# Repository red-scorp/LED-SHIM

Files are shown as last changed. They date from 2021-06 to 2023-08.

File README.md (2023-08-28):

# LED-SHIM project

LED-SHIM (mini-HAT), RGB LED array for Raspberry Pi.

Sometimes it's nice to add some shine to your Pi.
This can be achieved with a line or matrix of RGB addressable LEDs.
Welcome to a new shiny world!

## LED-mini20-SHIM

Raspberry Pi mini 40-pin **LED-mini20-SHIM** mini-HAT.

Preview:

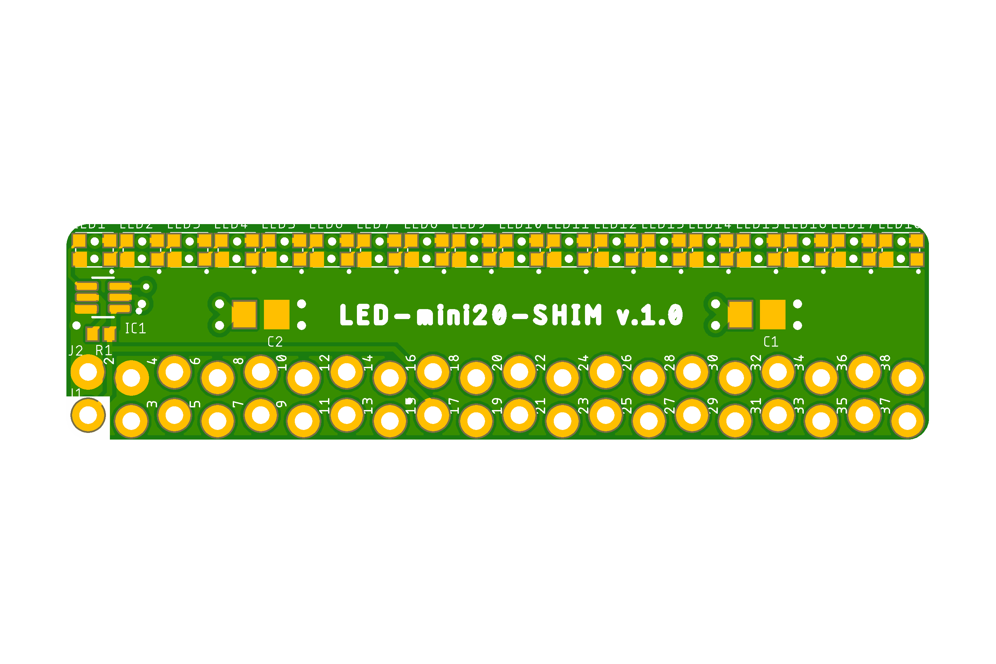
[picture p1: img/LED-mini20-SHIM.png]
LED-mini20-SHIM preview


[Schematics in PDF format](doc/LED-mini20-SHIM.pdf)

Features:

- locked Pi headers
- data input pin selection
- 18 RGB LEDs organized in a single line
- industry standard WS2812 addressable LEDs
- small board for Pi
- can be used as SHIM (no headers) or HAT (with headers)

Pins Configuration:

|Data Pin |Option 1 |Option 2 |Option 3 |
|---|---|---|---|
|DI |GPIO18\* |GPIO10 |GPIO21 |

\*) the pin is connected by default.

CAM files are available.
BoM and PnP files for JLCPCB are available.

## LED-mini35-SHIM

Raspberry Pi mini 40-pin **LED-mini35-SHIM** mini-HAT.

Preview:

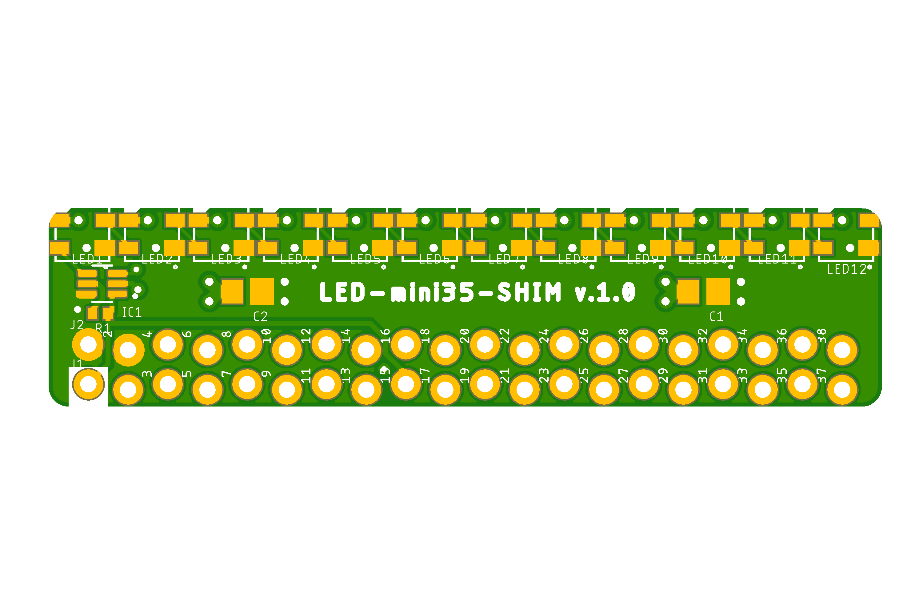
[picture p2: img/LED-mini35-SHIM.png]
LED-mini35-SHIM preview


[Schematics in PDF format](doc/LED-mini35-SHIM.pdf)

Features:

- locked Pi headers
- data input pin selection
- 12 RGB LEDs organized in a single line
- industry standard WS2812 addressable LEDs
- small board for Pi
- can be used as SHIM (no headers) or HAT (with headers)

Pins Configuration:

|Data Pin |Option 1 |Option 2 |Option 3 |
|---|---|---|---|
|DI |GPIO18\* |GPIO10 |GPIO21 |

\*) the pin is connected by default.

CAM files are available.
BoM and PnP files for JLCPCB are available.

## LED-zero20-SHIM

Raspberry Pi zero 40-pin **LED-zero20-SHIM** mini-HAT.

Preview:

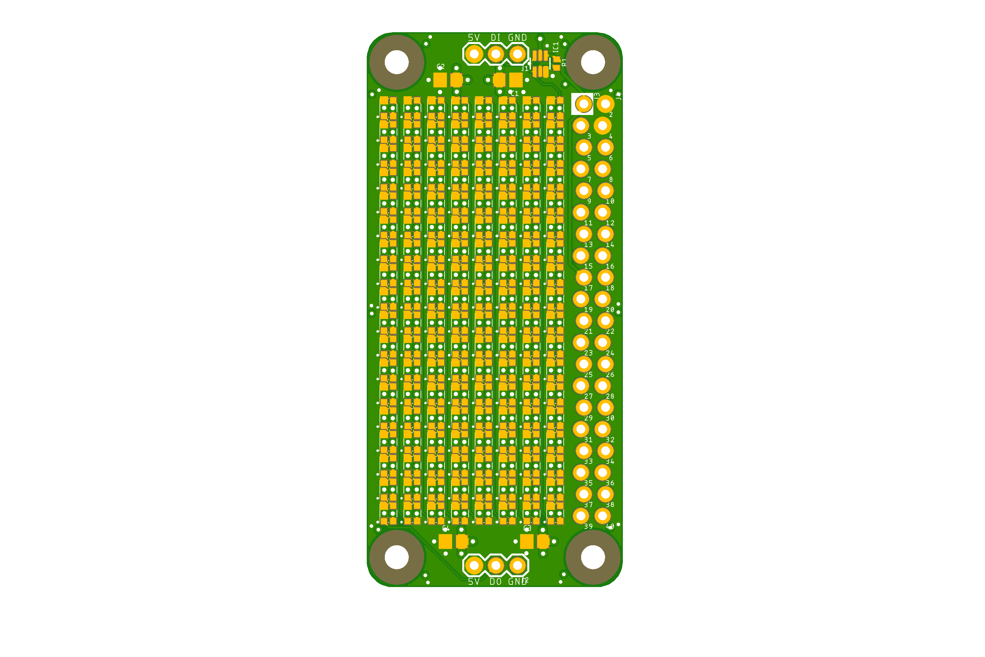
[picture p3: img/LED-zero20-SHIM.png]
LED-zero20-SHIM preview


[Schematics in PDF format](doc/LED-zero20-SHIM.pdf)

Features:

- locked Pi headers
- data input pin selection
- 144 RGB LEDs organized in a matrix of 18x8
- industry standard WS2812 addressable LEDs
- separate DI and DO headers for extendability
- Pi zero board style
- can be used as SHIM (no headers) or HAT (with headers)

Pins Configuration:

|Data Pin |Option 1 |Option 2 |Option 3 |
|---|---|---|---|
|DI |GPIO18\* |GPIO10 |GPIO21 |

\*) the pin is connected by default.

CAM files are available.
BoM and PnP files for JLCPCB are available.

## LED-zero35-SHIM

Raspberry Pi zero 40-pin **LED-zero35-SHIM** mini-HAT.

Preview:

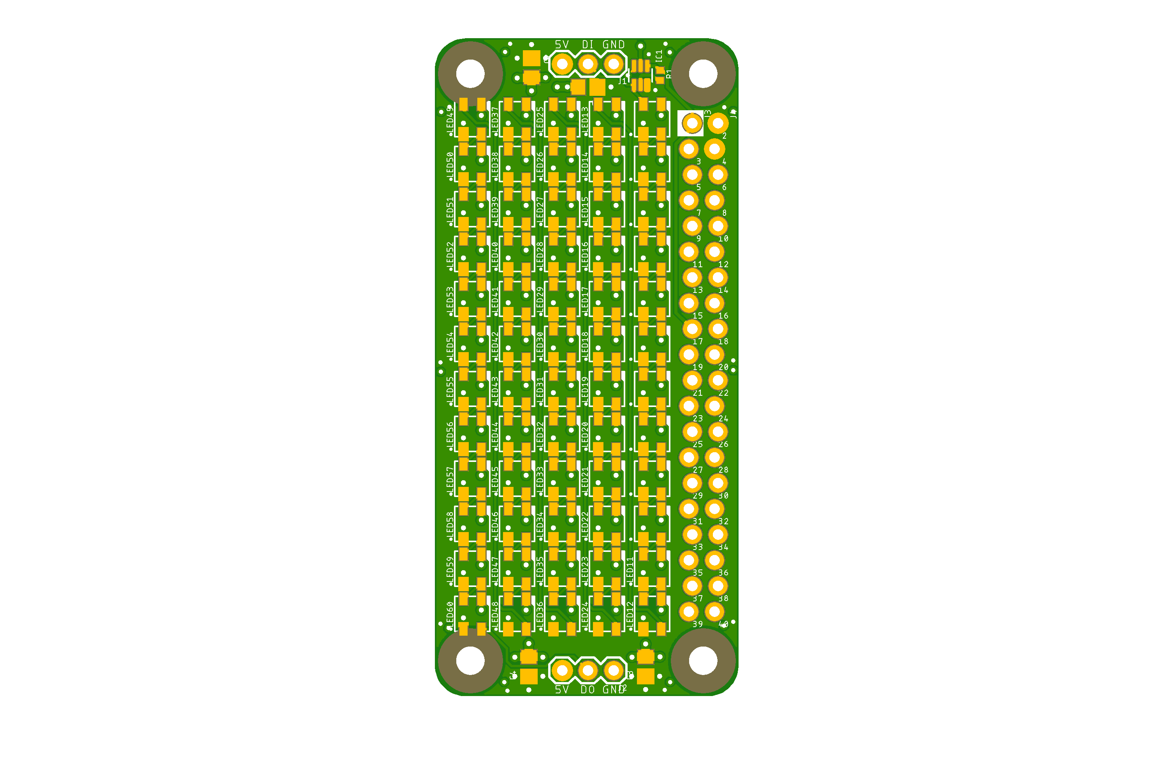
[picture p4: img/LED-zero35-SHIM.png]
LED-zero35-SHIM preview


[Schematics in PDF format](LED-zero35-SHIM.pdf)

Features:

- locked Pi headers
- data input pin selection
- 60 RGB LEDs organized in a matrix of 12x5
- industry standard WS2812 addressable LEDs
- separate DI and DO headers for extendability
- Pi zero board style
- can be used as SHIM (no headers) or HAT (with headers)

Pins Configuration:

|Data Pin |Option 1 |Option 2 |Option 3 |
|---|---|---|---|
|DI |GPIO18\* |GPIO10 |GPIO21 |

\*) the pin is connected by default.

CAM files are available.
BoM and PnP files for JLCPCB are available.

## LED-plus20-SHIM

Raspberry Pi plus 40-pin **LED-plus20-SHIM** mini-HAT.

Preview:

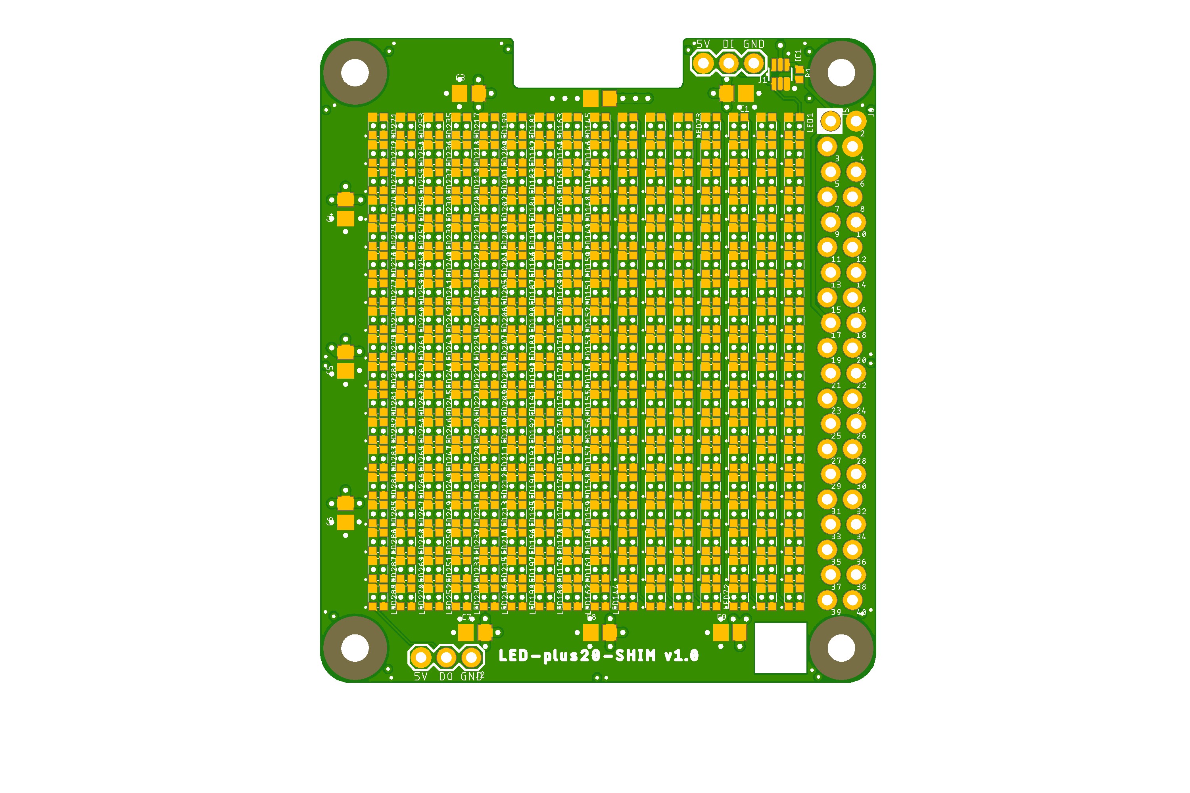
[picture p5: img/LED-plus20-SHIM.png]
LED-plus20-SHIM preview


[Schematics in PDF format](doc/LED-plus20-SHIM.pdf)

Features:

- locked Pi headers
- data input pin selection
- 288 RGB LEDs organized in a matrix of 18x16
- industry standard WS2812 addressable LEDs
- separate DI and DO headers for extendability
- Pi plus board style
- can be used as SHIM (no headers) or HAT (with headers)

Pins Configuration:

|Data Pin |Option 1 |Option 2 |Option 3 |
|---|---|---|---|
|DI |GPIO18\* |GPIO10 |GPIO21 |

\*) the pin is connected by default.

CAM files are available.
BoM and PnP files for JLCPCB are available.

## LED-plus35-SHIM

Raspberry Pi plus 40-pin **LED-plus35-SHIM** mini-HAT.

Preview:

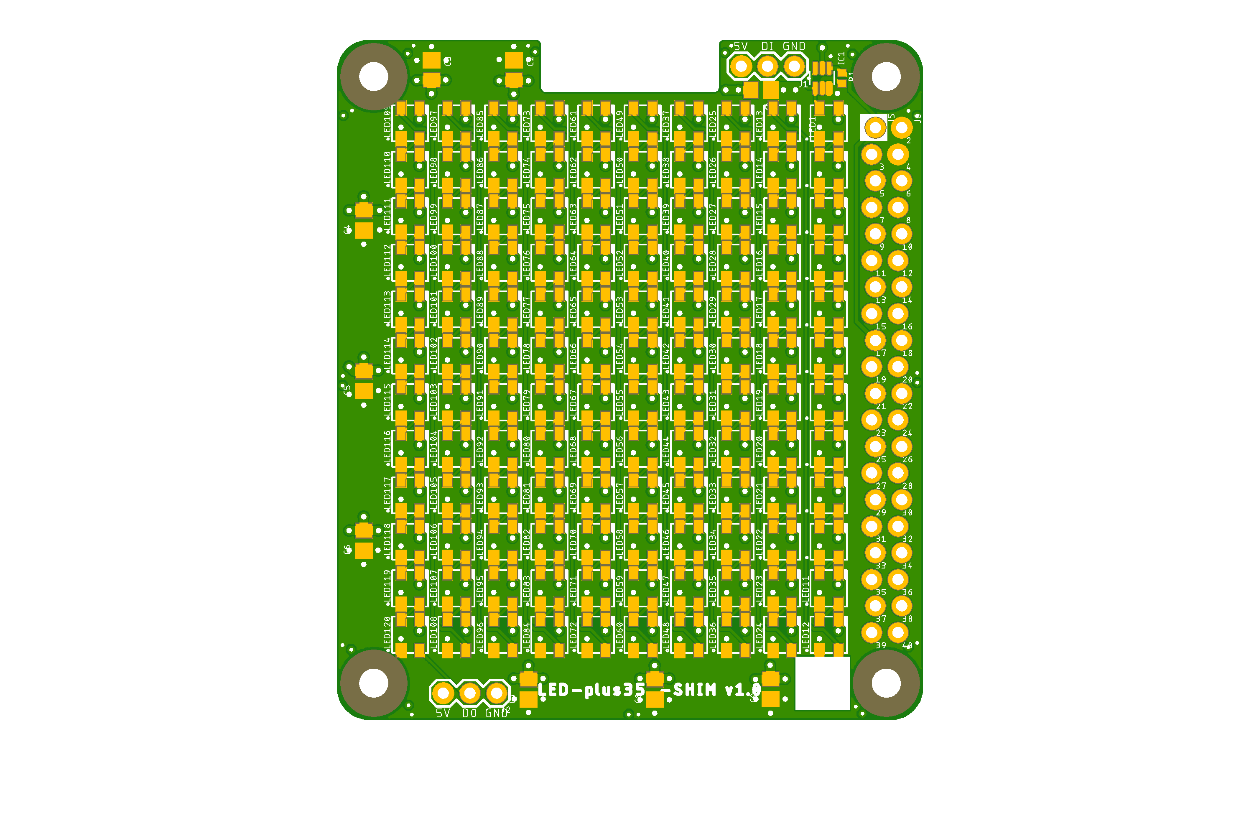
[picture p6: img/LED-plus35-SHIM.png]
LED-plus35-SHIM preview


[Schematics in PDF format](doc/LED-plus35-SHIM.pdf)

Features:

- locked Pi headers
- data input pin selection
- 120 RGB LEDs organized in a matrix of 12x10
- industry standard WS2812 addressable LEDs
- separate DI and DO headers for extendability
- Pi plus board style
- can be used as SHIM (no headers) or HAT (with headers)

Pins Configuration:

|Data Pin |Option 1 |Option 2 |Option 3 |
|---|---|---|---|
|DI |GPIO18\* |GPIO10 |GPIO21 |

\*) the pin is connected by default.

CAM files are available.
BoM and PnP files for JLCPCB are available.

## Links

- [pinout.xyz](https://pinout.xyz/) - a brilliant resource on topic of Pi's pinout and HATs.
- [raspberrypi/hats](https://github.com/raspberrypi/hats) - Pi's HAT specification.

## How to help

Your contributions as code, resources, or finances are welcome! Please contact me directly via email at andriy.golovnya@gmail.com or through my [GitHub profile](https://github.com/red-scorp).

If you'd like to make a financial contribution, you can donate via [PayPal](http://paypal.me/redscorp) or [Ko-Fi](http://ko-fi.com/redscorp). Your support is greatly appreciated.

Thanks in advance!

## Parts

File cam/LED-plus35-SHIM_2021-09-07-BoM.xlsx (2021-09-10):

Qty | Designator | Footprint | Comment | LCSC Part #
1 | R1 | 0402 | 10K | C25744 (https://lcsc.com/product-detail/Chip-Resistor-Surface-Mount_UNI-ROYAL-Uniroyal-Elec-0402WGF1002TCE_C25744.html/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)
9 | C1, C2, C3, C4, C5, C6, C7, C8, C9 | 0805 | 10uF | C15850 (https://lcsc.com/product-detail/Multilayer-Ceramic-Capacitors-MLCC-SMD-SMT_Samsung-Electro-Mechanics-CL21A106KAYNNNE_C15850.html/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)
1 | IC1 | SC-70-6 | TXB0101DCKR | C324081 (https://lcsc.com/product-detail/Level-Translators-Shifters_Texas-Instruments-TXB0101DCKR_C324081.html/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)
120 | LED1, LED2, LED3, LED4, LED5, LED6, LED7, LED8, LED9, LED10, LED11, LED12, LED13, LED14, LED15, LED16, LED17, LED18, LED19, LED20, LED21, LED22, LED23, LED24, LED25, LED26, LED27, LED28, LED29, LED30, LED31, LED32, LED33, LED34, LED35, LED36, LED37, LED38, LED39, LED40, LED41, LED42, LED43, LED44, LED45, LED46, LED47, LED48, LED49, LED50, LED51, LED52, LED53, LED54, LED55, LED56, LED57, LED58, LED59, LED60, LED61, LED62, LED63, LED64, LED65, LED66, LED67, LED68, LED69, LED70, LED71, LED72, LED73, LED74, LED75, LED76, LED77, LED78, LED79, LED80, LED81, LED82, LED83, LED84, LED85, LED86, LED87, LED88, LED89, LED90, LED91, LED92, LED93, LED94, LED95, LED96, LED97, LED98, LED99, LED100, LED101, LED102, LED103, LED104, LED105, LED106, LED107, LED108, LED109, LED110, LED111, LED112, LED113, LED114, LED115, LED116, LED117, LED118, LED119, LED120 | LED-4_3535 | WS2812B-MINI | C114583

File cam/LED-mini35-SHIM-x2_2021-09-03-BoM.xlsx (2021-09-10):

Qty | Designator | Footprint | Comment | LCSC Part #
2 | R1, R2 | 0402 | 10K | C25744 (https://lcsc.com/product-detail/Chip-Resistor-Surface-Mount_UNI-ROYAL-Uniroyal-Elec-0402WGF1002TCE_C25744.html/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)
2 | C1, C2, C3, C4 | 0805 | 10uF | C15850 (https://lcsc.com/product-detail/Multilayer-Ceramic-Capacitors-MLCC-SMD-SMT_Samsung-Electro-Mechanics-CL21A106KAYNNNE_C15850.html/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)
2 | IC1, IC2 | SC-70-6 | TXB0101DCKR | C324081 (https://lcsc.com/product-detail/Level-Translators-Shifters_Texas-Instruments-TXB0101DCKR_C324081.html/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)
12 | LED1, LED2, LED3, LED4, LED5, LED6, LED7, LED8, LED9, LED10, LED11, LED12, LED13, LED14, LED15, LED16, LED17, LED18, LED19, LED20, LED21, LED22, LED23, LED24 | LED-4_3535 | WS2812B-MINI | C114583

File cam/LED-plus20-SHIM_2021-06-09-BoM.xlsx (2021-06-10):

Qty | Designator | Footprint | Comment | LCSC Part #
1 | R1 | 0402 | 10K | C25744 (https://lcsc.com/product-detail/Chip-Resistor-Surface-Mount_UNI-ROYAL-Uniroyal-Elec-0402WGF1002TCE_C25744.html/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)
9 | C1, C2, C3, C4, C5, C6, C7, C8, C9 | 0805 | 10uF | C15850 (https://lcsc.com/product-detail/Multilayer-Ceramic-Capacitors-MLCC-SMD-SMT_Samsung-Electro-Mechanics-CL21A106KAYNNNE_C15850.html/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)
1 | IC1 | SC-70-6 | TXB0101DCKR | C324081 (https://lcsc.com/product-detail/Level-Translators-Shifters_Texas-Instruments-TXB0101DCKR_C324081.html/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)
288 | LED1, LED2, LED3, LED4, LED5, LED6, LED7, LED8, LED9, LED10, LED11, LED12, LED13, LED14, LED15, LED16, LED17, LED18, LED19, LED20, LED21, LED22, LED23, LED24, LED25, LED26, LED27, LED28, LED29, LED30, LED31, LED32, LED33, LED34, LED35, LED36, LED37, LED38, LED39, LED40, LED41, LED42, LED43, LED44, LED45, LED46, LED47, LED48, LED49, LED50, LED51, LED52, LED53, LED54, LED55, LED56, LED57, LED58, LED59, LED60, LED61, LED62, LED63, LED64, LED65, LED66, LED67, LED68, LED69, LED70, LED71, LED72, LED73, LED74, LED75, LED76, LED77, LED78, LED79, LED80, LED81, LED82, LED83, LED84, LED85, LED86, LED87, LED88, LED89, LED90, LED91, LED92, LED93, LED94, LED95, LED96, LED97, LED98, LED99, LED100, LED101, LED102, LED103, LED104, LED105, LED106, LED107, LED108, LED109, LED110, LED111, LED112, LED113, LED114, LED115, LED116, LED117, LED118, LED119, LED120, LED121, LED122, LED123, LED124, LED125, LED126, LED127, LED128, LED129, LED130, LED131, LED132, LED133, LED134, LED135, LED136, LED137, LED138, LED139, LED140, LED141, LED142, LED143, LED144, LED145, LED146, LED147, LED148, LED149, LED150, LED151, LED152, LED153, LED154, LED155, LED156, LED157, LED158, LED159, LED160, LED161, LED162, LED163, LED164, LED165, LED166, LED167, LED168, LED169, LED170, LED171, LED172, LED173, LED174, LED175, LED176, LED177, LED178, LED179, LED180, LED181, LED182, LED183, LED184, LED185, LED186, LED187, LED188, LED189, LED190, LED191, LED192, LED193, LED194, LED195, LED196, LED197, LED198, LED199, LED200, LED201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 | LED-4_2.0x2.0x1.1P | WS2812C-2020 | C965556 (https://lcsc.com/product-detail/Light-Emitting-Diodes-LED_Worldsemi-WS2812C-2020_C965556.html/?href=jlc-SMT)

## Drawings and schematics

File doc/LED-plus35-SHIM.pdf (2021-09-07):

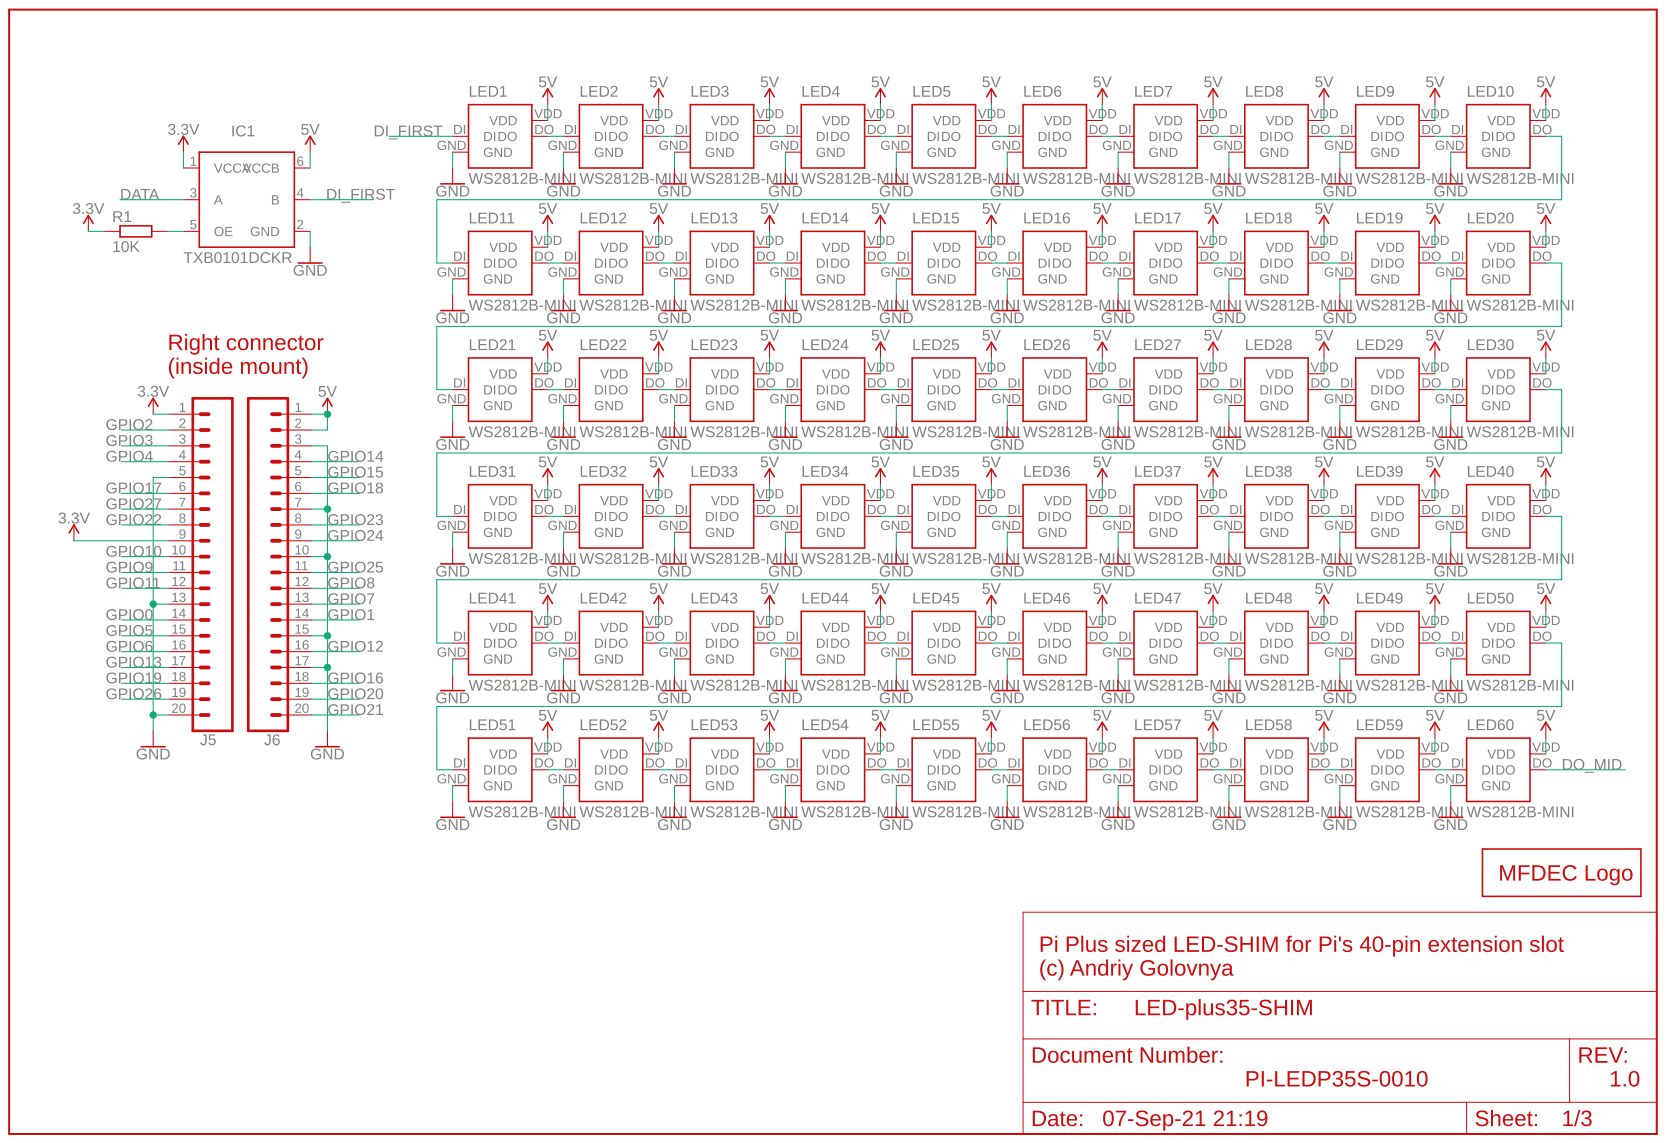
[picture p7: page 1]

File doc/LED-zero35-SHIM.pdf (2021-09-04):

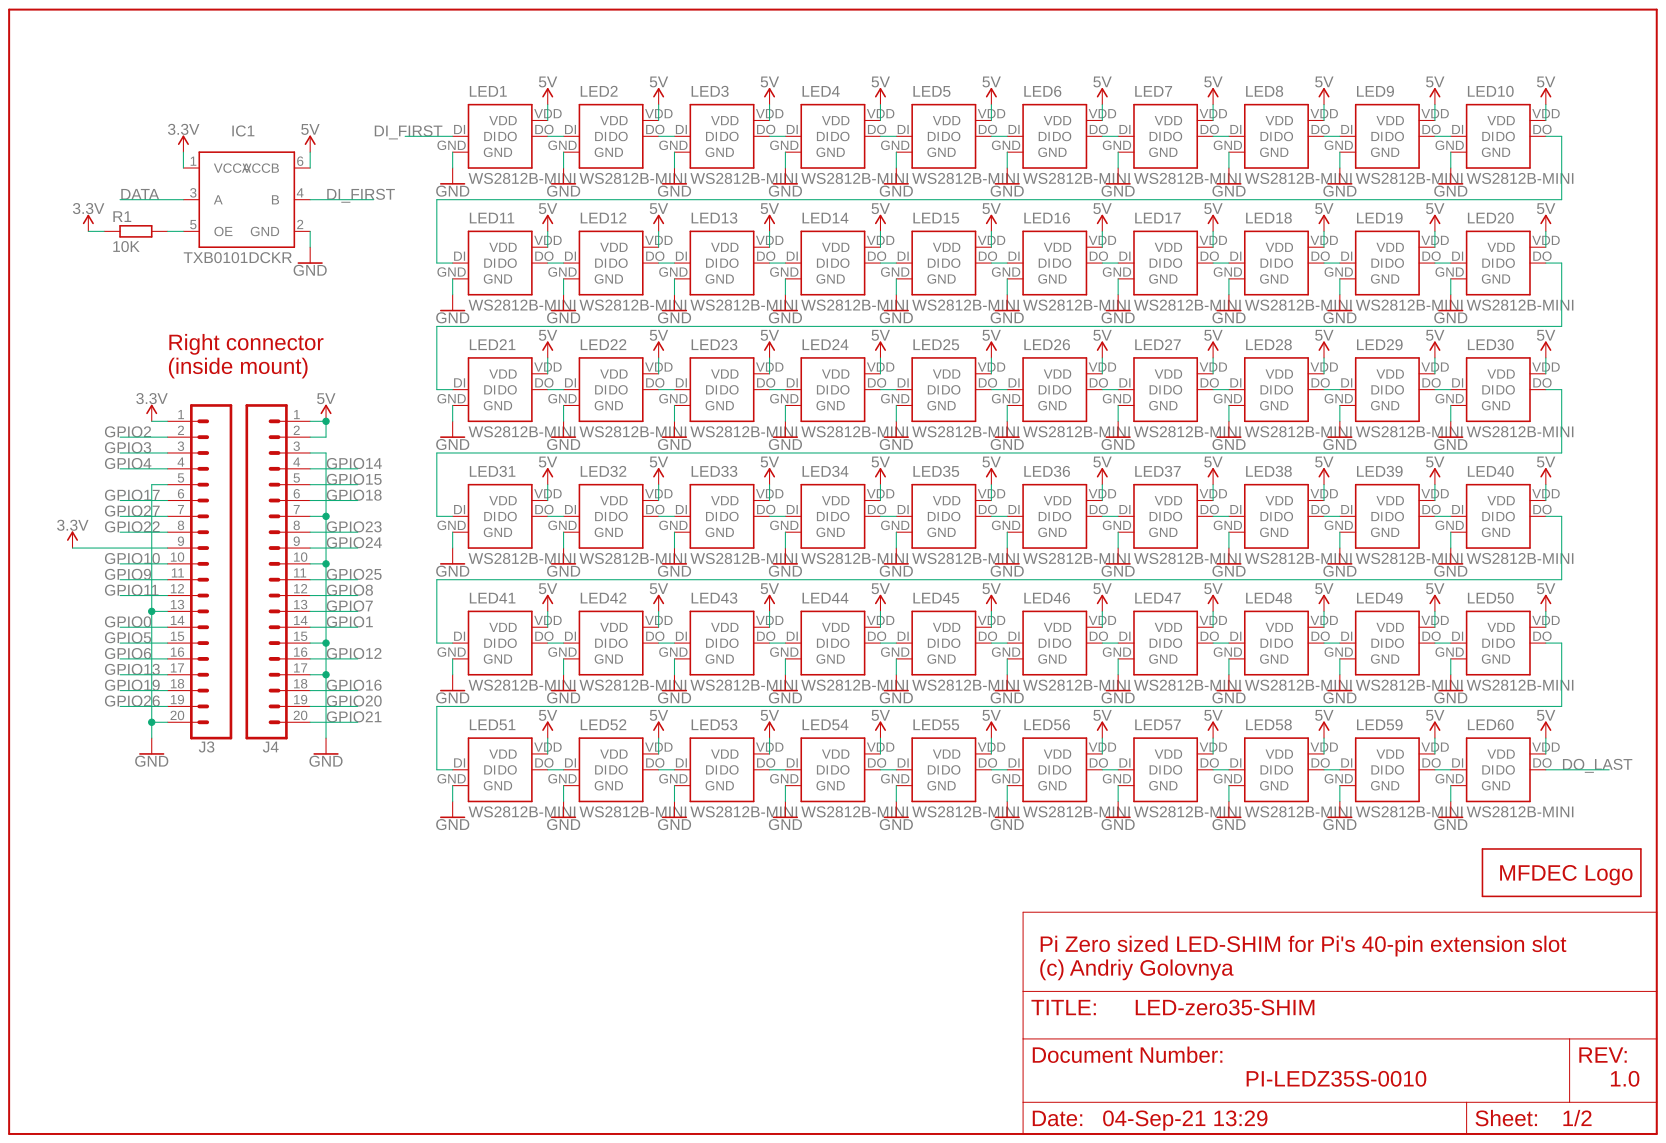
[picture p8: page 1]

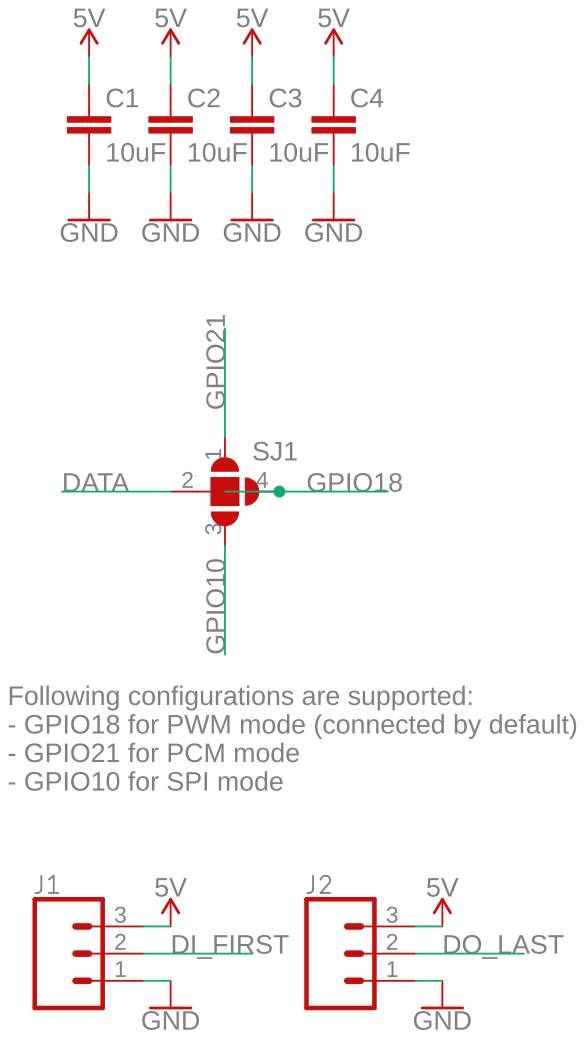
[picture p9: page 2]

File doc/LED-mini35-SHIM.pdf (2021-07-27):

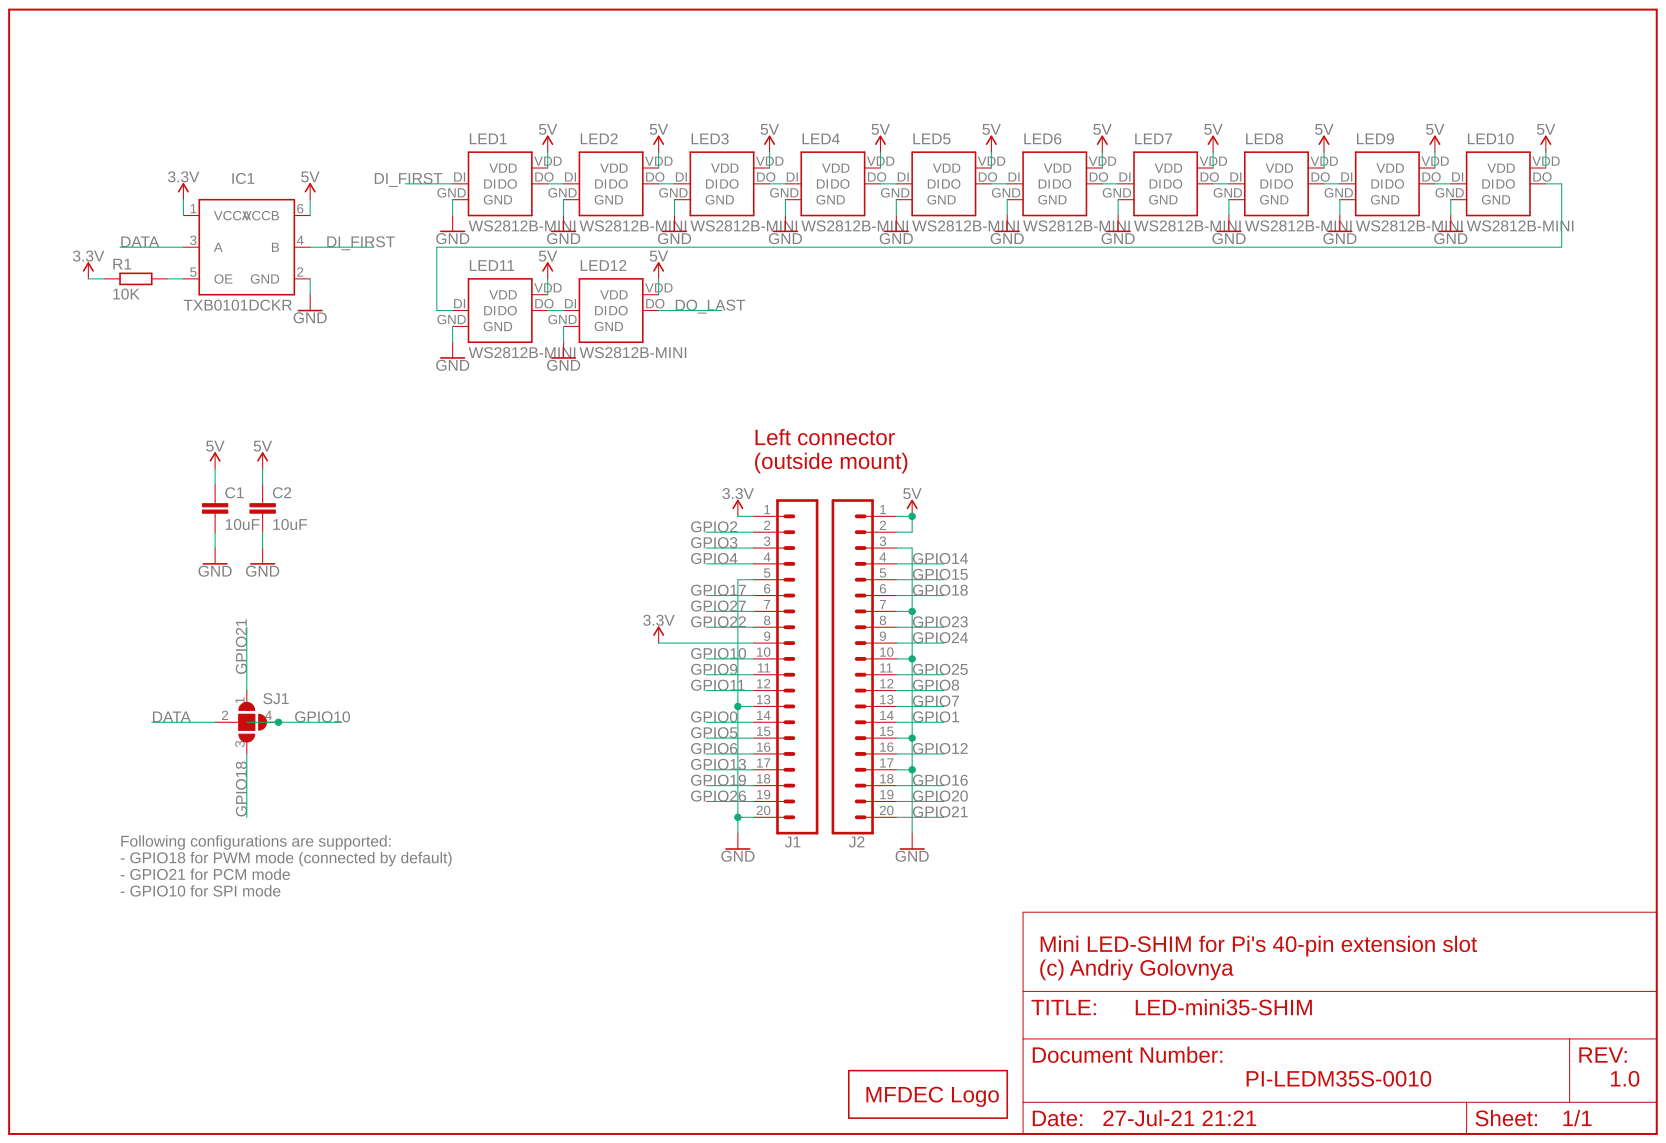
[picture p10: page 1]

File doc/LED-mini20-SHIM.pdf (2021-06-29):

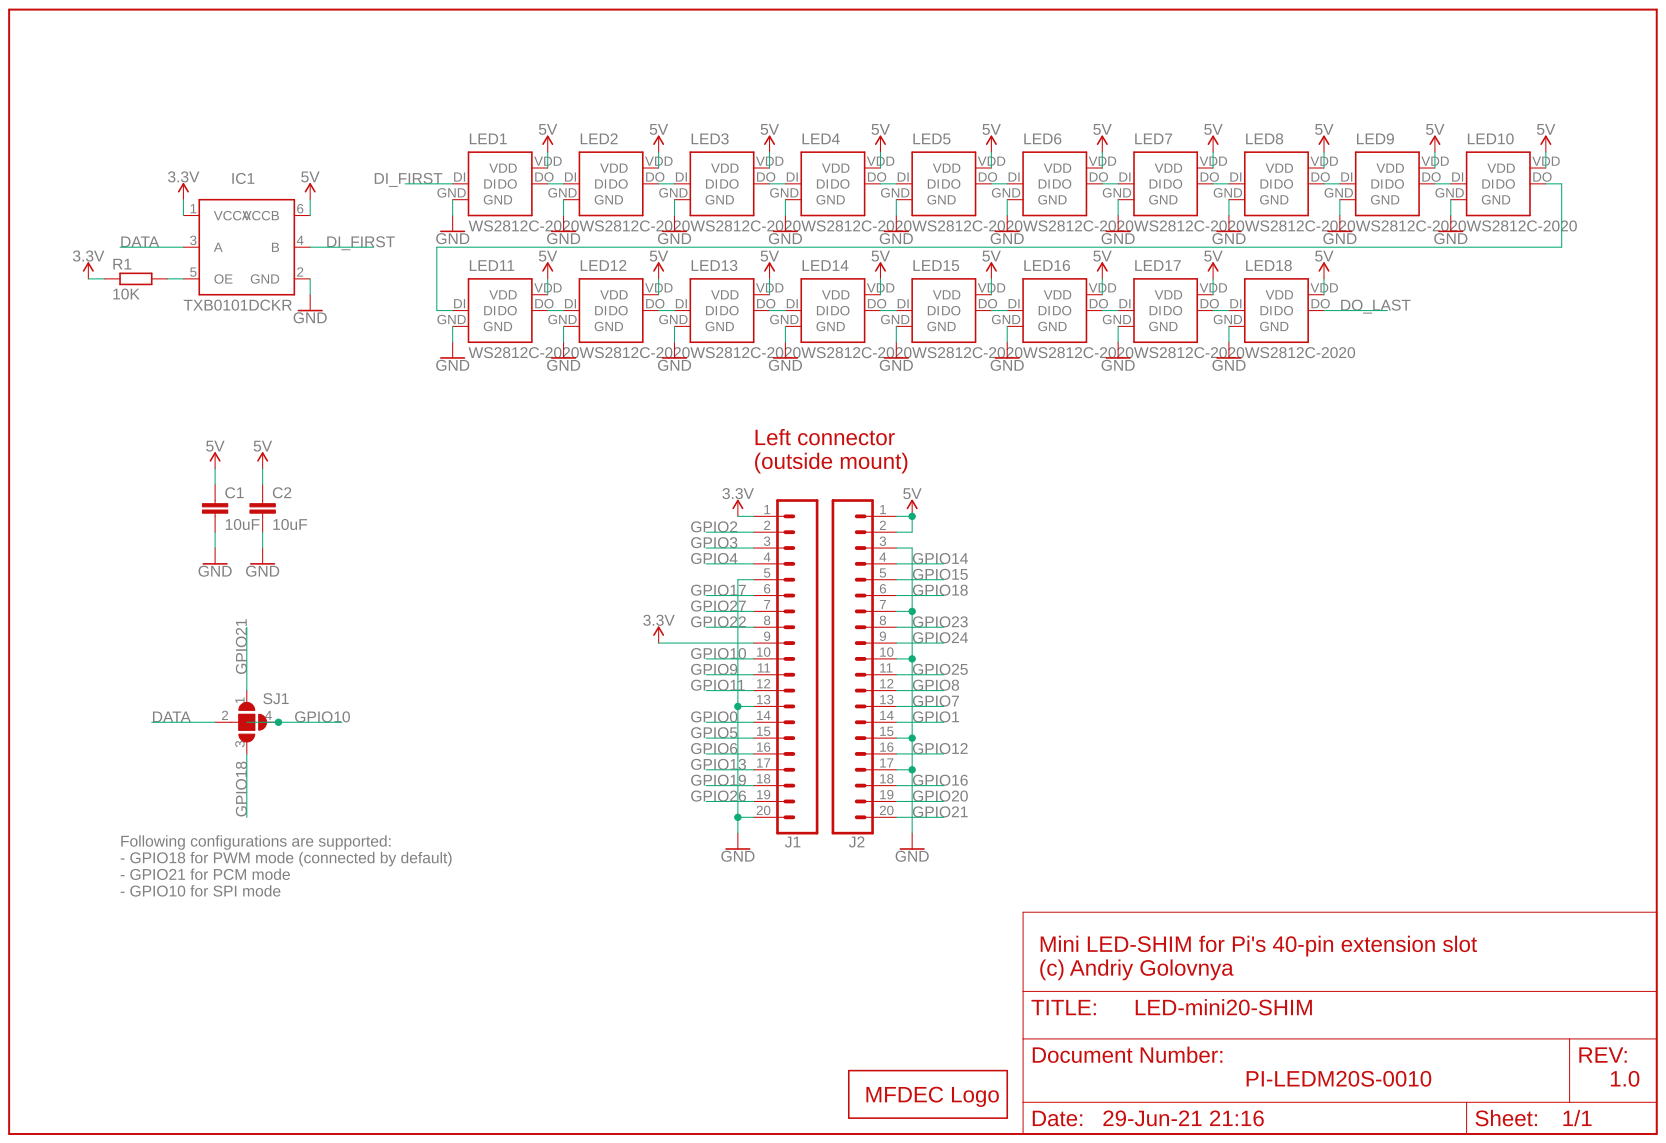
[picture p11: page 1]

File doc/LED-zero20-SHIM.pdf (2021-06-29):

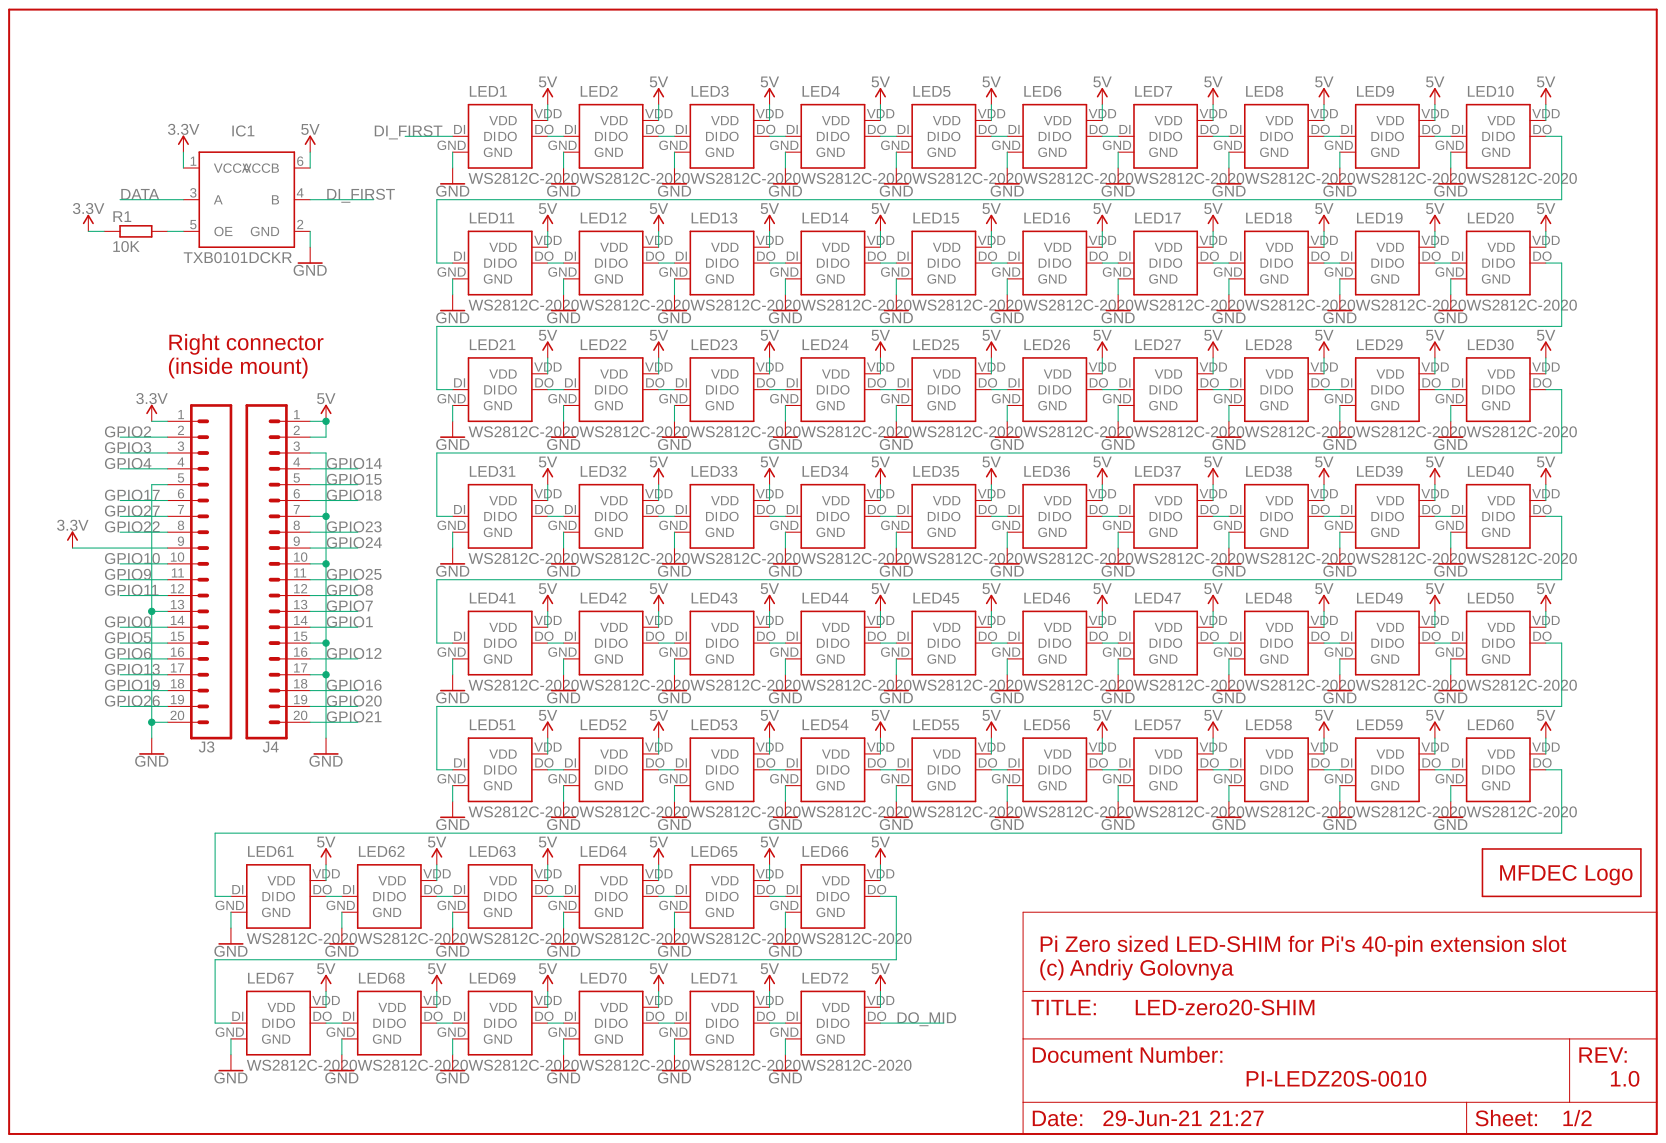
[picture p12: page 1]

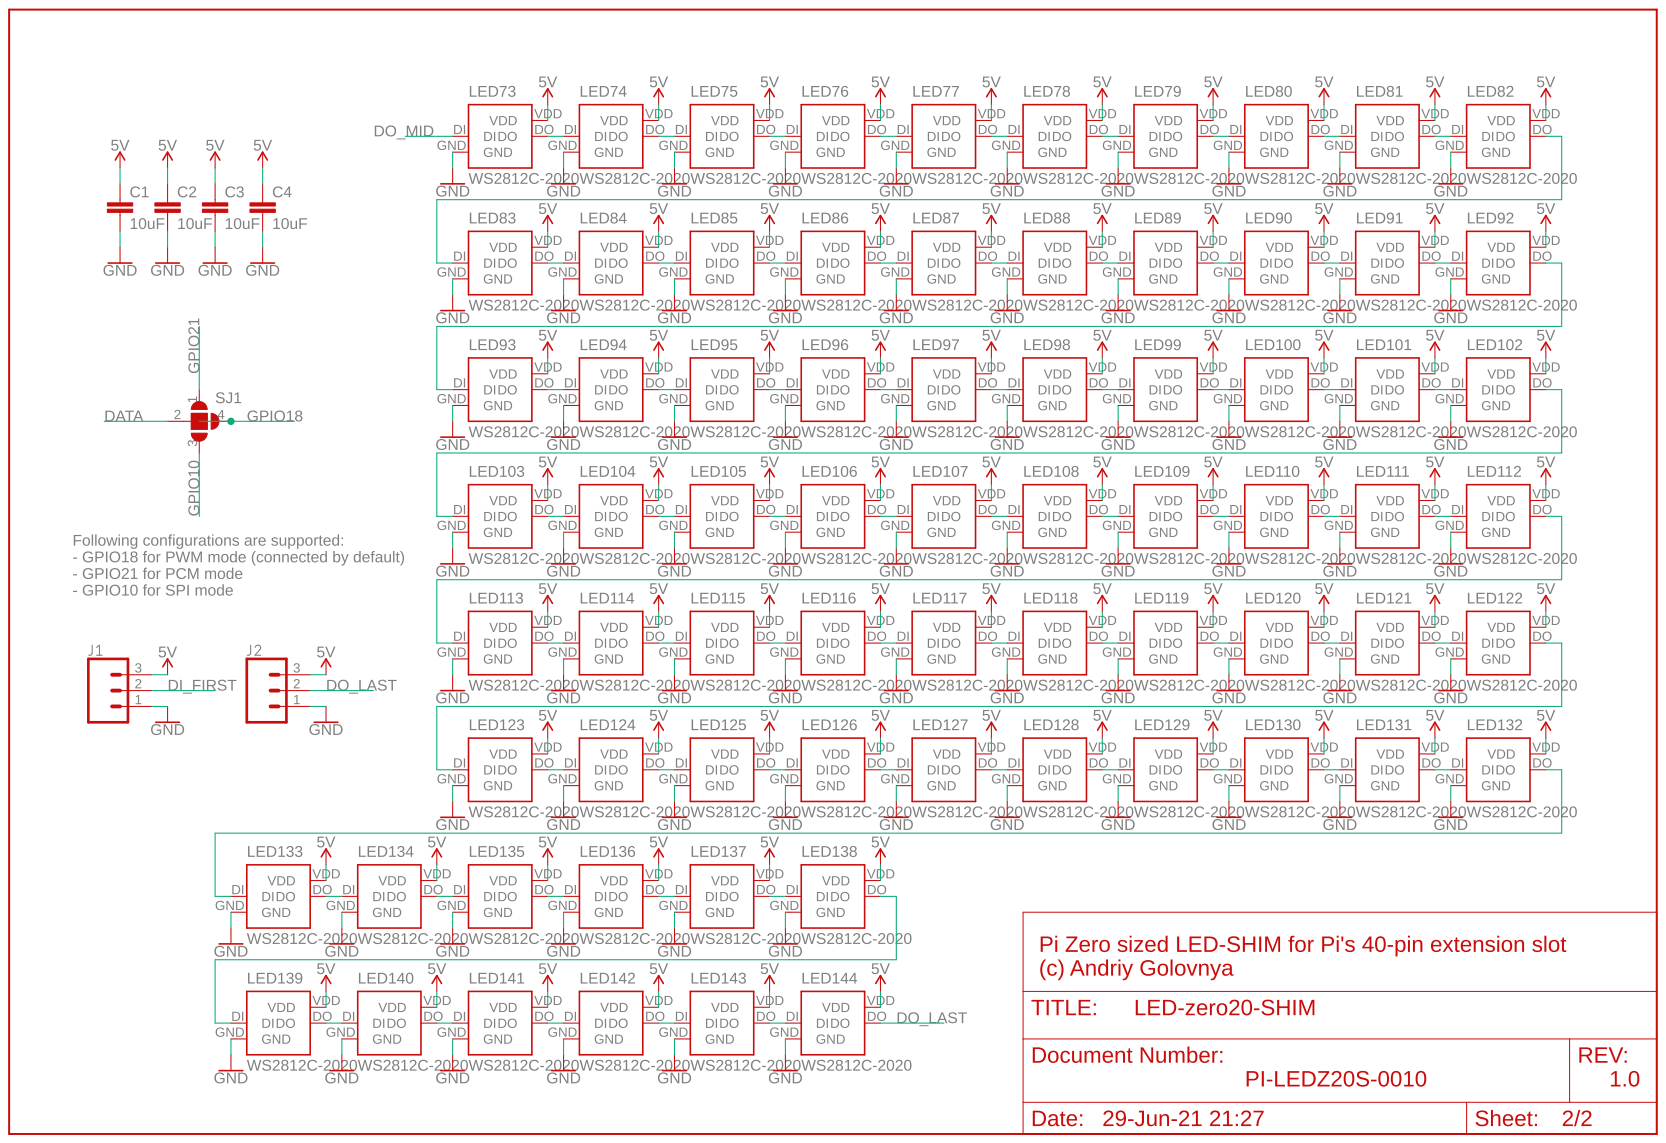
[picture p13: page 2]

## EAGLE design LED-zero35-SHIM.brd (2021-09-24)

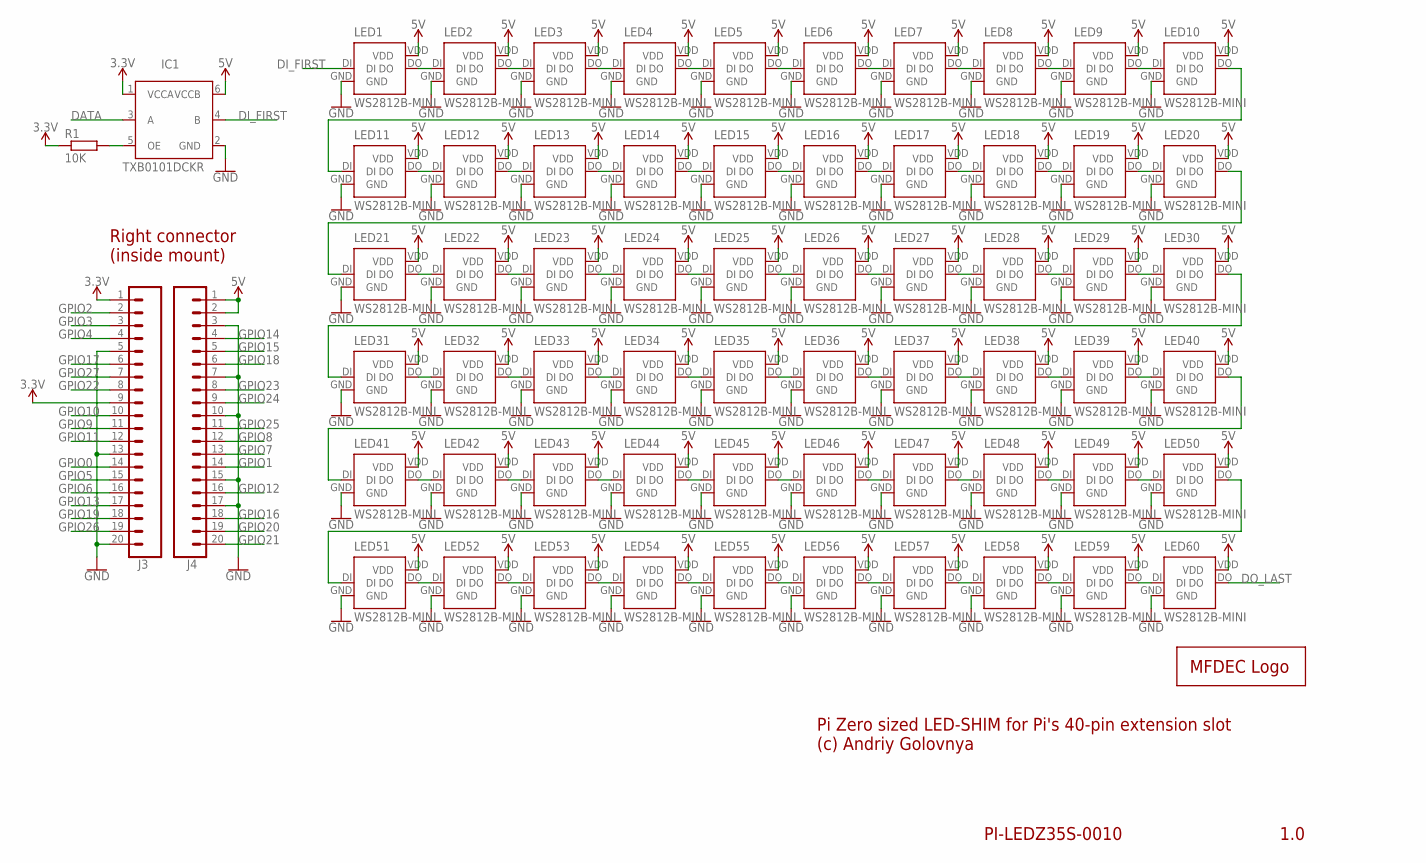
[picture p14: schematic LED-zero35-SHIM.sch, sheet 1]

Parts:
IC1: TXB0101DCKR; SOT65P210X110-6N
J3, J4: CONN_20LOCK; 1X20_LOCK
LED1, LED2, LED3, LED4, LED5, LED6, LED7, LED8, LED9, LED10, LED11, LED12, LED13, LED14, LED15, LED16, LED17, LED18, LED19, LED20, LED21, LED22, LED23, LED24, LED25, LED26, LED27, LED28, LED29, LED30, LED31, LED32, LED33, LED34, LED35, LED36, LED37, LED38, LED39, LED40, LED41, LED42, LED43, LED44, LED45, LED46, LED47, LED48, LED49, LED50, LED51, LED52, LED53, LED54, LED55, LED56, LED57, LED58, LED59, LED60: WS2812B-MINI; WS2812X-MINI
LOGO1: MFDECLOGO_L_30MM; MFDEC_L_30MM
R1: 10K; R0402

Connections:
3.3V: IC1.1 (VCCA), J3.1, J3.9, R1.1
5V: IC1.6 (VCCB), J4.1, J4.2, LED1.VDD, LED2.VDD, LED3.VDD, LED4.VDD, LED5.VDD, LED6.VDD, LED7.VDD, LED8.VDD, LED9.VDD, LED10.VDD, LED11.VDD, LED12.VDD, LED13.VDD, LED14.VDD, LED15.VDD, LED16.VDD, LED17.VDD, LED18.VDD, LED19.VDD, LED20.VDD, LED21.VDD, LED22.VDD, LED23.VDD, LED24.VDD, LED25.VDD, LED26.VDD, LED27.VDD, LED28.VDD, LED29.VDD, LED30.VDD, LED31.VDD, LED32.VDD, LED33.VDD, LED34.VDD, LED35.VDD, LED36.VDD, LED37.VDD, LED38.VDD, LED39.VDD, LED40.VDD, LED41.VDD, LED42.VDD, LED43.VDD, LED44.VDD, LED45.VDD, LED46.VDD, LED47.VDD, LED48.VDD, LED49.VDD, LED50.VDD, LED51.VDD, LED52.VDD, LED53.VDD, LED54.VDD, LED55.VDD, LED56.VDD, LED57.VDD, LED58.VDD, LED59.VDD, LED60.VDD; also elsewhere on the board
DATA: IC1.3 (A); also elsewhere on the board
DI_FIRST: IC1.4 (B), LED1.DI; also elsewhere on the board
DO_LAST: LED60.DO; also elsewhere on the board
GND: IC1.2 (GND), J3.5, J3.13, J3.20, J4.3, J4.7, J4.10, J4.15, J4.17, LED1.GND, LED2.GND, LED3.GND, LED4.GND, LED5.GND, LED6.GND, LED7.GND, LED8.GND, LED9.GND, LED10.GND, LED11.GND, LED12.GND, LED13.GND, LED14.GND, LED15.GND, LED16.GND, LED17.GND, LED18.GND, LED19.GND, LED20.GND, LED21.GND, LED22.GND, LED23.GND, LED24.GND, LED25.GND, LED26.GND, LED27.GND, LED28.GND, LED29.GND, LED30.GND, LED31.GND, LED32.GND, LED33.GND, LED34.GND, LED35.GND, LED36.GND, LED37.GND, LED38.GND, LED39.GND, LED40.GND, LED41.GND, LED42.GND, LED43.GND, LED44.GND, LED45.GND, LED46.GND, LED47.GND, LED48.GND, LED49.GND, LED50.GND, LED51.GND, LED52.GND, LED53.GND, LED54.GND, LED55.GND, LED56.GND, LED57.GND, LED58.GND, LED59.GND, LED60.GND; also elsewhere on the board
GPIO0: J3.14
GPIO1: J4.14
GPIO2: J3.2
GPIO3: J3.3
GPIO4: J3.4
GPIO5: J3.15
GPIO6: J3.16
GPIO7: J4.13
GPIO8: J4.12
GPIO9: J3.11
GPIO10: J3.10; also elsewhere on the board
GPIO11: J3.12
GPIO12: J4.16
GPIO13: J3.17
GPIO14: J4.4
GPIO15: J4.5
GPIO16: J4.18
GPIO17: J3.6
GPIO18: J4.6; also elsewhere on the board
GPIO19: J3.18
GPIO20: J4.19
GPIO21: J4.20; also elsewhere on the board
GPIO22: J3.8
GPIO23: J4.8
GPIO24: J4.9
GPIO25: J4.11
GPIO26: J3.19
GPIO27: J3.7
unnamed: LED1.DO, LED2.DI
unnamed: LED2.DO, LED3.DI
unnamed: LED3.DO, LED4.DI
unnamed: LED4.DO, LED5.DI
unnamed: LED5.DO, LED6.DI
unnamed: LED6.DO, LED7.DI
unnamed: LED7.DO, LED8.DI
unnamed: LED8.DO, LED9.DI
unnamed: LED9.DO, LED10.DI
unnamed: LED10.DO, LED11.DI
unnamed: LED11.DO, LED12.DI
unnamed: LED12.DO, LED13.DI
unnamed: LED13.DO, LED14.DI
unnamed: LED14.DO, LED15.DI
unnamed: LED15.DO, LED16.DI
unnamed: LED16.DO, LED17.DI
unnamed: LED17.DO, LED18.DI
unnamed: LED18.DO, LED19.DI
unnamed: LED19.DO, LED20.DI
unnamed: LED20.DO, LED21.DI
unnamed: LED21.DO, LED22.DI
unnamed: LED22.DO, LED23.DI
unnamed: LED23.DO, LED24.DI
unnamed: LED24.DO, LED25.DI
unnamed: LED25.DO, LED26.DI
unnamed: LED26.DO, LED27.DI
unnamed: LED27.DO, LED28.DI
unnamed: LED28.DO, LED29.DI
unnamed: LED29.DO, LED30.DI
unnamed: LED30.DO, LED31.DI
unnamed: LED41.DO, LED42.DI
unnamed: LED31.DO, LED32.DI
unnamed: LED32.DO, LED33.DI
unnamed: LED33.DO, LED34.DI
unnamed: LED34.DO, LED35.DI
unnamed: LED35.DO, LED36.DI
unnamed: LED36.DO, LED37.DI
unnamed: LED37.DO, LED38.DI
unnamed: LED38.DO, LED39.DI
unnamed: LED39.DO, LED40.DI
unnamed: LED40.DO, LED41.DI
unnamed: LED42.DO, LED43.DI
unnamed: LED43.DO, LED44.DI
unnamed: LED44.DO, LED45.DI
unnamed: LED45.DO, LED46.DI
unnamed: LED46.DO, LED47.DI
unnamed: LED47.DO, LED48.DI
unnamed: LED48.DO, LED49.DI
unnamed: LED49.DO, LED50.DI
unnamed: LED50.DO, LED51.DI
unnamed: LED51.DO, LED52.DI
unnamed: LED52.DO, LED53.DI
unnamed: LED53.DO, LED54.DI
unnamed: LED54.DO, LED55.DI
unnamed: LED55.DO, LED56.DI
unnamed: LED56.DO, LED57.DI
unnamed: LED57.DO, LED58.DI
unnamed: LED58.DO, LED59.DI
unnamed: LED59.DO, LED60.DI
unnamed: IC1.5 (OE), R1.2

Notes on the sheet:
1.0
PI-LEDZ35S-0010
Pi Zero sized LED-SHIM for Pi's 40-pin extension slot (c) Andriy Golovnya
Right connector (inside mount)

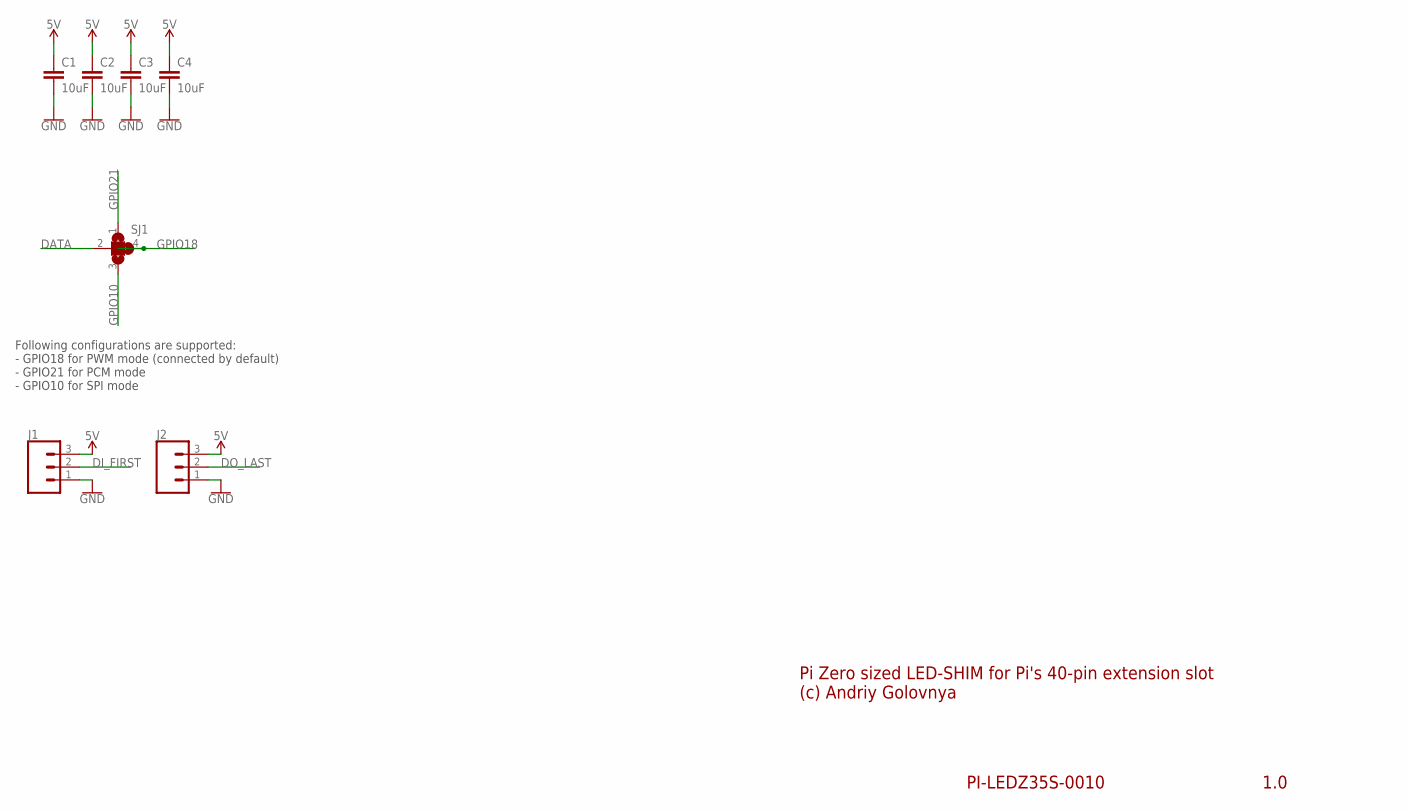
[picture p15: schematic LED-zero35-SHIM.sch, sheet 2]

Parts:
C1, C2, C3, C4: 10uF; C0805
J1, J2: CONN_03; 1X03
SJ1: SJ3; SJ_3

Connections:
5V: C1.1, C2.1, C3.1, C4.1, J1.3, J2.3; also elsewhere on the board
DATA: SJ1.2; also elsewhere on the board
DI_FIRST: J1.2; also elsewhere on the board
DO_LAST: J2.2; also elsewhere on the board
GND: C1.2, C2.2, C3.2, C4.2, J1.1, J2.1; also elsewhere on the board
GPIO10: SJ1.3; also elsewhere on the board
GPIO18: SJ1.4; also elsewhere on the board
GPIO21: SJ1.1; also elsewhere on the board

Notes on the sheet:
1.0
PI-LEDZ35S-0010
Pi Zero sized LED-SHIM for Pi's 40-pin extension slot (c) Andriy Golovnya
Following configurations are supported: - GPIO18 for PWM mode (connected by default) - GPIO21 for PCM mode - GPIO10 for SPI mode

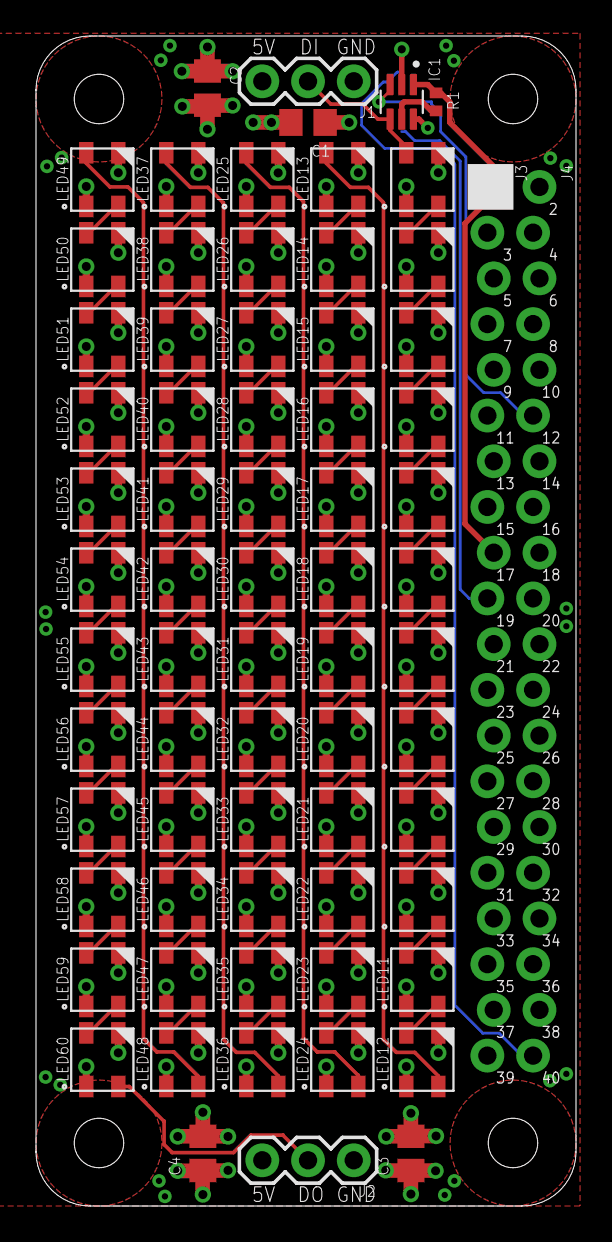
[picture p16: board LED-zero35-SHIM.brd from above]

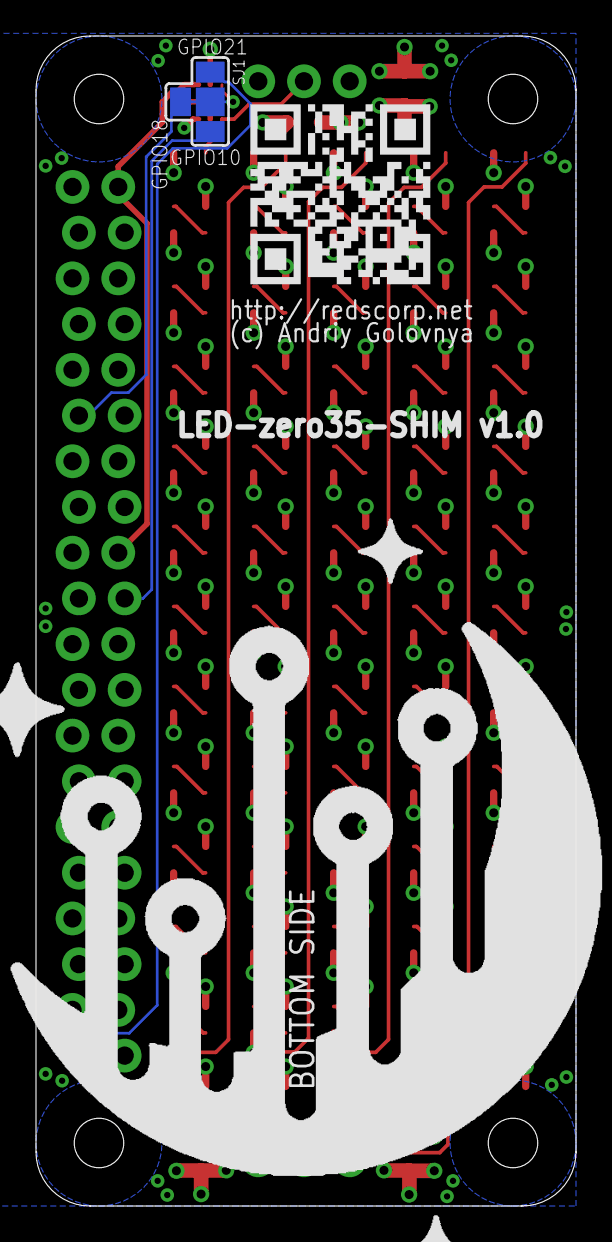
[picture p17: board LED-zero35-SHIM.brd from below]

Board: 4 copper layers, 30.0 x 65.0 mm, 73 parts (3 on the bottom side), 69 nets.

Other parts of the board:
LOGO3: RSNURL_QR_10MM

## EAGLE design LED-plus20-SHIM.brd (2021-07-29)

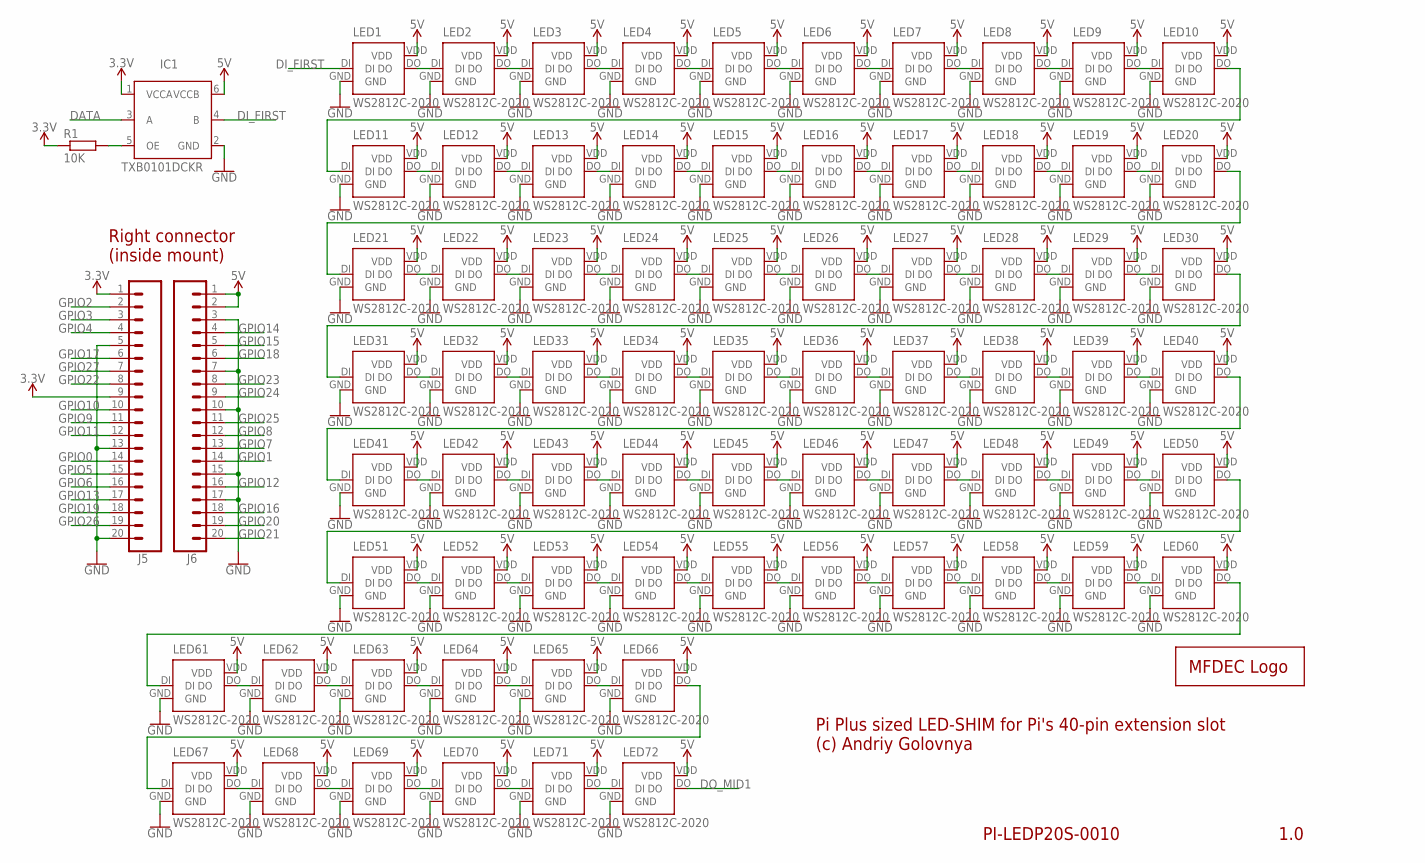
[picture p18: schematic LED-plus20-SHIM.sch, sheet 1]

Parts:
IC1: TXB0101DCKR; SOT65P210X110-6N
J5, J6: CONN_20LOCK; 1X20_LOCK
LED1, LED2, LED3, LED4, LED5, LED6, LED7, LED8, LED9, LED10, LED11, LED12, LED13, LED14, LED15, LED16, LED17, LED18, LED19, LED20, LED21, LED22, LED23, LED24, LED25, LED26, LED27, LED28, LED29, LED30, LED31, LED32, LED33, LED34, LED35, LED36, LED37, LED38, LED39, LED40, LED41, LED42, LED43, LED44, LED45, LED46, LED47, LED48, LED49, LED50, LED51, LED52, LED53, LED54, LED55, LED56, LED57, LED58, LED59, LED60, LED61, LED62, LED63, LED64, LED65, LED66, LED67, LED68, LED69, LED70, LED71, LED72: WS2812C-2020; WS2812X-2020
LOGO1: MFDECLOGO_L_40MM; MFDEC_L_40MM
R1: 10K; R0402

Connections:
3.3V: IC1.1 (VCCA), J5.1, J5.9, R1.1
5V: IC1.6 (VCCB), J6.1, J6.2, LED1.VDD, LED2.VDD, LED3.VDD, LED4.VDD, LED5.VDD, LED6.VDD, LED7.VDD, LED8.VDD, LED9.VDD, LED10.VDD, LED11.VDD, LED12.VDD, LED13.VDD, LED14.VDD, LED15.VDD, LED16.VDD, LED17.VDD, LED18.VDD, LED19.VDD, LED20.VDD, LED21.VDD, LED22.VDD, LED23.VDD, LED24.VDD, LED25.VDD, LED26.VDD, LED27.VDD, LED28.VDD, LED29.VDD, LED30.VDD, LED31.VDD, LED32.VDD, LED33.VDD, LED34.VDD, LED35.VDD, LED36.VDD, LED37.VDD, LED38.VDD, LED39.VDD, LED40.VDD, LED41.VDD, LED42.VDD, LED43.VDD, LED44.VDD, LED45.VDD, LED46.VDD, LED47.VDD, LED48.VDD, LED49.VDD, LED50.VDD, LED51.VDD, LED52.VDD, LED53.VDD, LED54.VDD, LED55.VDD, LED56.VDD, LED57.VDD, LED58.VDD, LED59.VDD, LED60.VDD, LED61.VDD, LED62.VDD, LED63.VDD, LED64.VDD, LED65.VDD, LED66.VDD, LED67.VDD, LED68.VDD, LED69.VDD, LED70.VDD, LED71.VDD, LED72.VDD; also elsewhere on the board
DATA: IC1.3 (A); also elsewhere on the board
DI_FIRST: IC1.4 (B), LED1.DI; also elsewhere on the board
DO_MID1: LED72.DO; also elsewhere on the board
GND: IC1.2 (GND), J5.5, J5.13, J5.20, J6.3, J6.7, J6.10, J6.15, J6.17, LED1.GND, LED2.GND, LED3.GND, LED4.GND, LED5.GND, LED6.GND, LED7.GND, LED8.GND, LED9.GND, LED10.GND, LED11.GND, LED12.GND, LED13.GND, LED14.GND, LED15.GND, LED16.GND, LED17.GND, LED18.GND, LED19.GND, LED20.GND, LED21.GND, LED22.GND, LED23.GND, LED24.GND, LED25.GND, LED26.GND, LED27.GND, LED28.GND, LED29.GND, LED30.GND, LED31.GND, LED32.GND, LED33.GND, LED34.GND, LED35.GND, LED36.GND, LED37.GND, LED38.GND, LED39.GND, LED40.GND, LED41.GND, LED42.GND, LED43.GND, LED44.GND, LED45.GND, LED46.GND, LED47.GND, LED48.GND, LED49.GND, LED50.GND, LED51.GND, LED52.GND, LED53.GND, LED54.GND, LED55.GND, LED56.GND, LED57.GND, LED58.GND, LED59.GND, LED60.GND, LED61.GND, LED62.GND, LED63.GND, LED64.GND, LED65.GND, LED66.GND, LED67.GND, LED68.GND, LED69.GND, LED70.GND, LED71.GND, LED72.GND; also elsewhere on the board
GPIO0: J5.14
GPIO1: J6.14
GPIO2: J5.2
GPIO3: J5.3
GPIO4: J5.4
GPIO5: J5.15
GPIO6: J5.16
GPIO7: J6.13
GPIO8: J6.12
GPIO9: J5.11
GPIO10: J5.10; also elsewhere on the board
GPIO11: J5.12
GPIO12: J6.16
GPIO13: J5.17
GPIO14: J6.4
GPIO15: J6.5
GPIO16: J6.18
GPIO17: J5.6
GPIO18: J6.6; also elsewhere on the board
GPIO19: J5.18
GPIO20: J6.19
GPIO21: J6.20; also elsewhere on the board
GPIO22: J5.8
GPIO23: J6.8
GPIO24: J6.9
GPIO25: J6.11
GPIO26: J5.19
GPIO27: J5.7
unnamed: LED1.DO, LED2.DI
unnamed: LED2.DO, LED3.DI
unnamed: LED3.DO, LED4.DI
unnamed: LED4.DO, LED5.DI
unnamed: LED5.DO, LED6.DI
unnamed: LED6.DO, LED7.DI
unnamed: LED7.DO, LED8.DI
unnamed: LED8.DO, LED9.DI
unnamed: LED9.DO, LED10.DI
unnamed: LED10.DO, LED11.DI
unnamed: LED11.DO, LED12.DI
unnamed: LED12.DO, LED13.DI
unnamed: LED13.DO, LED14.DI
unnamed: LED14.DO, LED15.DI
unnamed: LED15.DO, LED16.DI
unnamed: LED16.DO, LED17.DI
unnamed: LED17.DO, LED18.DI
unnamed: LED18.DO, LED19.DI
unnamed: LED19.DO, LED20.DI
unnamed: LED20.DO, LED21.DI
unnamed: LED21.DO, LED22.DI
unnamed: LED22.DO, LED23.DI
unnamed: LED23.DO, LED24.DI
unnamed: LED24.DO, LED25.DI
unnamed: LED25.DO, LED26.DI
unnamed: LED26.DO, LED27.DI
unnamed: LED27.DO, LED28.DI
unnamed: LED28.DO, LED29.DI
unnamed: LED29.DO, LED30.DI
unnamed: LED30.DO, LED31.DI
unnamed: LED31.DO, LED32.DI
unnamed: LED32.DO, LED33.DI
unnamed: LED33.DO, LED34.DI
unnamed: LED34.DO, LED35.DI
unnamed: LED35.DO, LED36.DI
unnamed: LED36.DO, LED37.DI
unnamed: LED37.DO, LED38.DI
unnamed: LED38.DO, LED39.DI
unnamed: LED39.DO, LED40.DI
unnamed: LED40.DO, LED41.DI
unnamed: LED41.DO, LED42.DI
unnamed: LED42.DO, LED43.DI
unnamed: LED43.DO, LED44.DI
unnamed: LED44.DO, LED45.DI
unnamed: LED45.DO, LED46.DI
unnamed: LED46.DO, LED47.DI
unnamed: LED47.DO, LED48.DI
unnamed: LED48.DO, LED49.DI
unnamed: LED49.DO, LED50.DI
unnamed: LED50.DO, LED51.DI
unnamed: LED51.DO, LED52.DI
unnamed: LED52.DO, LED53.DI
unnamed: LED53.DO, LED54.DI
unnamed: LED54.DO, LED55.DI
unnamed: LED55.DO, LED56.DI
unnamed: LED56.DO, LED57.DI
unnamed: LED57.DO, LED58.DI
unnamed: LED58.DO, LED59.DI
unnamed: LED59.DO, LED60.DI
unnamed: LED60.DO, LED61.DI
unnamed: LED61.DO, LED62.DI
unnamed: LED62.DO, LED63.DI
unnamed: LED63.DO, LED64.DI
unnamed: LED64.DO, LED65.DI
unnamed: LED65.DO, LED66.DI
unnamed: LED66.DO, LED67.DI
unnamed: LED67.DO, LED68.DI
unnamed: LED68.DO, LED69.DI
unnamed: LED69.DO, LED70.DI
unnamed: LED70.DO, LED71.DI
unnamed: LED71.DO, LED72.DI
unnamed: IC1.5 (OE), R1.2

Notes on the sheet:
1.0
PI-LEDP20S-0010
Pi Plus sized LED-SHIM for Pi's 40-pin extension slot (c) Andriy Golovnya
Right connector (inside mount)

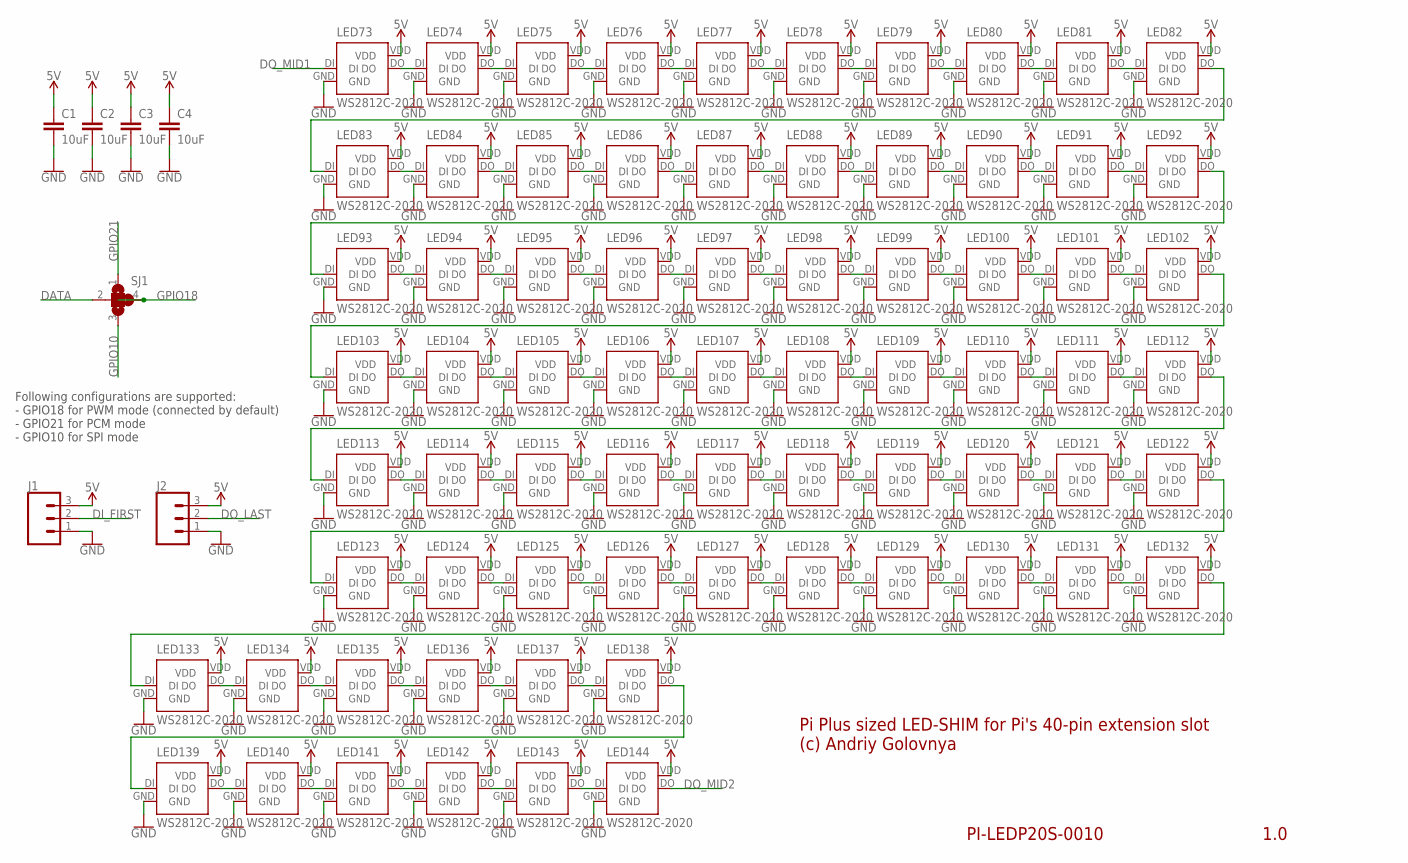
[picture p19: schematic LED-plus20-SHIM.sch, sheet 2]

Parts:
C1, C2, C3, C4: 10uF; C0805
J1, J2: CONN_03; 1X03
LED73, LED74, LED75, LED76, LED77, LED78, LED79, LED80, LED81, LED82, LED83, LED84, LED85, LED86, LED87, LED88, LED89, LED90, LED91, LED92, LED93, LED94, LED95, LED96, LED97, LED98, LED99, LED100, LED101, LED102, LED103, LED104, LED105, LED106, LED107, LED108, LED109, LED110, LED111, LED112, LED113, LED114, LED115, LED116, LED117, LED118, LED119, LED120, LED121, LED122, LED123, LED124, LED125, LED126, LED127, LED128, LED129, LED130, LED131, LED132, LED133, LED134, LED135, LED136, LED137, LED138, LED139, LED140, LED141, LED142, LED143, LED144: WS2812C-2020; WS2812X-2020
SJ1: SJ3; SJ_3

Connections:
5V: C1.1, C2.1, C3.1, C4.1, J1.3, J2.3, LED73.VDD, LED74.VDD, LED75.VDD, LED76.VDD, LED77.VDD, LED78.VDD, LED79.VDD, LED80.VDD, LED81.VDD, LED82.VDD, LED83.VDD, LED84.VDD, LED85.VDD, LED86.VDD, LED87.VDD, LED88.VDD, LED89.VDD, LED90.VDD, LED91.VDD, LED92.VDD, LED93.VDD, LED94.VDD, LED95.VDD, LED96.VDD, LED97.VDD, LED98.VDD, LED99.VDD, LED100.VDD, LED101.VDD, LED102.VDD, LED103.VDD, LED104.VDD, LED105.VDD, LED106.VDD, LED107.VDD, LED108.VDD, LED109.VDD, LED110.VDD, LED111.VDD, LED112.VDD, LED113.VDD, LED114.VDD, LED115.VDD, LED116.VDD, LED117.VDD, LED118.VDD, LED119.VDD, LED120.VDD, LED121.VDD, LED122.VDD, LED123.VDD, LED124.VDD, LED125.VDD, LED126.VDD, LED127.VDD, LED128.VDD, LED129.VDD, LED130.VDD, LED131.VDD, LED132.VDD, LED133.VDD, LED134.VDD, LED135.VDD, LED136.VDD, LED137.VDD, LED138.VDD, LED139.VDD, LED140.VDD, LED141.VDD, LED142.VDD, LED143.VDD, LED144.VDD; also elsewhere on the board
DATA: SJ1.2; also elsewhere on the board
DI_FIRST: J1.2; also elsewhere on the board
DO_LAST: J2.2; also elsewhere on the board
DO_MID1: LED73.DI; also elsewhere on the board
DO_MID2: LED144.DO; also elsewhere on the board
GND: C1.2, C2.2, C3.2, C4.2, J1.1, J2.1, LED73.GND, LED74.GND, LED75.GND, LED76.GND, LED77.GND, LED78.GND, LED79.GND, LED80.GND, LED81.GND, LED82.GND, LED83.GND, LED84.GND, LED85.GND, LED86.GND, LED87.GND, LED88.GND, LED89.GND, LED90.GND, LED91.GND, LED92.GND, LED93.GND, LED94.GND, LED95.GND, LED96.GND, LED97.GND, LED98.GND, LED99.GND, LED100.GND, LED101.GND, LED102.GND, LED103.GND, LED104.GND, LED105.GND, LED106.GND, LED107.GND, LED108.GND, LED109.GND, LED110.GND, LED111.GND, LED112.GND, LED113.GND, LED114.GND, LED115.GND, LED116.GND, LED117.GND, LED118.GND, LED119.GND, LED120.GND, LED121.GND, LED122.GND, LED123.GND, LED124.GND, LED125.GND, LED126.GND, LED127.GND, LED128.GND, LED129.GND, LED130.GND, LED131.GND, LED132.GND, LED133.GND, LED134.GND, LED135.GND, LED136.GND, LED137.GND, LED138.GND, LED139.GND, LED140.GND, LED141.GND, LED142.GND, LED143.GND, LED144.GND; also elsewhere on the board
GPIO10: SJ1.3; also elsewhere on the board
GPIO18: SJ1.4; also elsewhere on the board
GPIO21: SJ1.1; also elsewhere on the board
unnamed: LED73.DO, LED74.DI
unnamed: LED74.DO, LED75.DI
unnamed: LED75.DO, LED76.DI
unnamed: LED76.DO, LED77.DI
unnamed: LED77.DO, LED78.DI
unnamed: LED78.DO, LED79.DI
unnamed: LED79.DO, LED80.DI
unnamed: LED80.DO, LED81.DI
unnamed: LED81.DO, LED82.DI
unnamed: LED82.DO, LED83.DI
unnamed: LED83.DO, LED84.DI
unnamed: LED84.DO, LED85.DI
unnamed: LED85.DO, LED86.DI
unnamed: LED86.DO, LED87.DI
unnamed: LED87.DO, LED88.DI
unnamed: LED88.DO, LED89.DI
unnamed: LED89.DO, LED90.DI
unnamed: LED90.DO, LED91.DI
unnamed: LED91.DO, LED92.DI
unnamed: LED92.DO, LED93.DI
unnamed: LED93.DO, LED94.DI
unnamed: LED94.DO, LED95.DI
unnamed: LED95.DO, LED96.DI
unnamed: LED96.DO, LED97.DI
unnamed: LED97.DO, LED98.DI
unnamed: LED98.DO, LED99.DI
unnamed: LED99.DO, LED100.DI
unnamed: LED100.DO, LED101.DI
unnamed: LED101.DO, LED102.DI
unnamed: LED102.DO, LED103.DI
unnamed: LED103.DO, LED104.DI
unnamed: LED104.DO, LED105.DI
unnamed: LED105.DO, LED106.DI
unnamed: LED106.DO, LED107.DI
unnamed: LED107.DO, LED108.DI
unnamed: LED108.DO, LED109.DI
unnamed: LED109.DO, LED110.DI
unnamed: LED110.DO, LED111.DI
unnamed: LED111.DO, LED112.DI
unnamed: LED112.DO, LED113.DI
unnamed: LED113.DO, LED114.DI
unnamed: LED114.DO, LED115.DI
unnamed: LED115.DO, LED116.DI
unnamed: LED116.DO, LED117.DI
unnamed: LED117.DO, LED118.DI
unnamed: LED118.DO, LED119.DI
unnamed: LED119.DO, LED120.DI
unnamed: LED120.DO, LED121.DI
unnamed: LED121.DO, LED122.DI
unnamed: LED122.DO, LED123.DI
unnamed: LED123.DO, LED124.DI
unnamed: LED124.DO, LED125.DI
unnamed: LED125.DO, LED126.DI
unnamed: LED126.DO, LED127.DI
unnamed: LED127.DO, LED128.DI
unnamed: LED128.DO, LED129.DI
unnamed: LED129.DO, LED130.DI
unnamed: LED130.DO, LED131.DI
unnamed: LED131.DO, LED132.DI
unnamed: LED132.DO, LED133.DI
unnamed: LED133.DO, LED134.DI
unnamed: LED134.DO, LED135.DI
unnamed: LED135.DO, LED136.DI
unnamed: LED136.DO, LED137.DI
unnamed: LED137.DO, LED138.DI
unnamed: LED138.DO, LED139.DI
unnamed: LED139.DO, LED140.DI
unnamed: LED140.DO, LED141.DI
unnamed: LED141.DO, LED142.DI
unnamed: LED142.DO, LED143.DI
unnamed: LED143.DO, LED144.DI

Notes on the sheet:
1.0
PI-LEDP20S-0010
Pi Plus sized LED-SHIM for Pi's 40-pin extension slot (c) Andriy Golovnya
Following configurations are supported: - GPIO18 for PWM mode (connected by default) - GPIO21 for PCM mode - GPIO10 for SPI mode

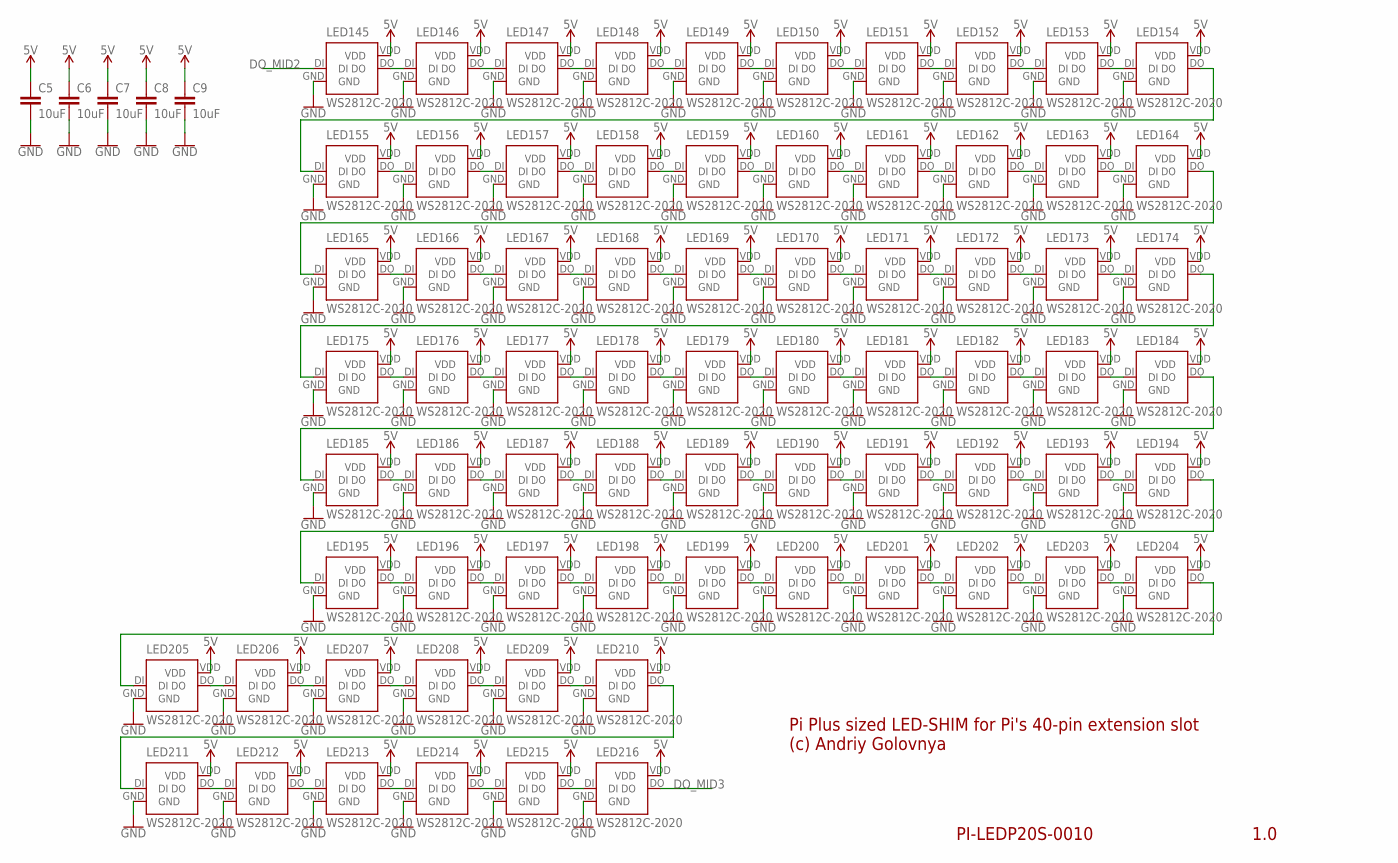
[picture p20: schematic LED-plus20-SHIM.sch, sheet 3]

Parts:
C5, C6, C7, C8, C9: 10uF; C0805
LED145, LED146, LED147, LED148, LED149, LED150, LED151, LED152, LED153, LED154, LED155, LED156, LED157, LED158, LED159, LED160, LED161, LED162, LED163, LED164, LED165, LED166, LED167, LED168, LED169, LED170, LED171, LED172, LED173, LED174, LED175, LED176, LED177, LED178, LED179, LED180, LED181, LED182, LED183, LED184, LED185, LED186, LED187, LED188, LED189, LED190, LED191, LED192, LED193, LED194, LED195, LED196, LED197, LED198, LED199, LED200, LED201, LED202, LED203, LED204, LED205, LED206, LED207, LED208, LED209, LED210, LED211, LED212, LED213, LED214, LED215, LED216: WS2812C-2020; WS2812X-2020

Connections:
5V: C5.1, C6.1, C7.1, C8.1, C9.1, LED145.VDD, LED146.VDD, LED147.VDD, LED148.VDD, LED149.VDD, LED150.VDD, LED151.VDD, LED152.VDD, LED153.VDD, LED154.VDD, LED155.VDD, LED156.VDD, LED157.VDD, LED158.VDD, LED159.VDD, LED160.VDD, LED161.VDD, LED162.VDD, LED163.VDD, LED164.VDD, LED165.VDD, LED166.VDD, LED167.VDD, LED168.VDD, LED169.VDD, LED170.VDD, LED171.VDD, LED172.VDD, LED173.VDD, LED174.VDD, LED175.VDD, LED176.VDD, LED177.VDD, LED178.VDD, LED179.VDD, LED180.VDD, LED181.VDD, LED182.VDD, LED183.VDD, LED184.VDD, LED185.VDD, LED186.VDD, LED187.VDD, LED188.VDD, LED189.VDD, LED190.VDD, LED191.VDD, LED192.VDD, LED193.VDD, LED194.VDD, LED195.VDD, LED196.VDD, LED197.VDD, LED198.VDD, LED199.VDD, LED200.VDD, LED201.VDD, LED202.VDD, LED203.VDD, LED204.VDD, LED205.VDD, LED206.VDD, LED207.VDD, LED208.VDD, LED209.VDD, LED210.VDD, LED211.VDD, LED212.VDD, LED213.VDD, LED214.VDD, LED215.VDD, LED216.VDD; also elsewhere on the board
DO_MID2: LED145.DI; also elsewhere on the board
DO_MID3: LED216.DO; also elsewhere on the board
GND: C5.2, C6.2, C7.2, C8.2, C9.2, LED145.GND, LED146.GND, LED147.GND, LED148.GND, LED149.GND, LED150.GND, LED151.GND, LED152.GND, LED153.GND, LED154.GND, LED155.GND, LED156.GND, LED157.GND, LED158.GND, LED159.GND, LED160.GND, LED161.GND, LED162.GND, LED163.GND, LED164.GND, LED165.GND, LED166.GND, LED167.GND, LED168.GND, LED169.GND, LED170.GND, LED171.GND, LED172.GND, LED173.GND, LED174.GND, LED175.GND, LED176.GND, LED177.GND, LED178.GND, LED179.GND, LED180.GND, LED181.GND, LED182.GND, LED183.GND, LED184.GND, LED185.GND, LED186.GND, LED187.GND, LED188.GND, LED189.GND, LED190.GND, LED191.GND, LED192.GND, LED193.GND, LED194.GND, LED195.GND, LED196.GND, LED197.GND, LED198.GND, LED199.GND, LED200.GND, LED201.GND, LED202.GND, LED203.GND, LED204.GND, LED205.GND, LED206.GND, LED207.GND, LED208.GND, LED209.GND, LED210.GND, LED211.GND, LED212.GND, LED213.GND, LED214.GND, LED215.GND, LED216.GND; also elsewhere on the board
unnamed: LED145.DO, LED146.DI
unnamed: LED146.DO, LED147.DI
unnamed: LED147.DO, LED148.DI
unnamed: LED148.DO, LED149.DI
unnamed: LED149.DO, LED150.DI
unnamed: LED150.DO, LED151.DI
unnamed: LED151.DO, LED152.DI
unnamed: LED152.DO, LED153.DI
unnamed: LED153.DO, LED154.DI
unnamed: LED154.DO, LED155.DI
unnamed: LED155.DO, LED156.DI
unnamed: LED156.DO, LED157.DI
unnamed: LED157.DO, LED158.DI
unnamed: LED158.DO, LED159.DI
unnamed: LED159.DO, LED160.DI
unnamed: LED160.DO, LED161.DI
unnamed: LED161.DO, LED162.DI
unnamed: LED162.DO, LED163.DI
unnamed: LED163.DO, LED164.DI
unnamed: LED164.DO, LED165.DI
unnamed: LED165.DO, LED166.DI
unnamed: LED166.DO, LED167.DI
unnamed: LED167.DO, LED168.DI
unnamed: LED168.DO, LED169.DI
unnamed: LED169.DO, LED170.DI
unnamed: LED170.DO, LED171.DI
unnamed: LED171.DO, LED172.DI
unnamed: LED172.DO, LED173.DI
unnamed: LED173.DO, LED174.DI
unnamed: LED174.DO, LED175.DI
unnamed: LED175.DO, LED176.DI
unnamed: LED176.DO, LED177.DI
unnamed: LED177.DO, LED178.DI
unnamed: LED178.DO, LED179.DI
unnamed: LED179.DO, LED180.DI
unnamed: LED180.DO, LED181.DI
unnamed: LED181.DO, LED182.DI
unnamed: LED182.DO, LED183.DI
unnamed: LED183.DO, LED184.DI
unnamed: LED184.DO, LED185.DI
unnamed: LED185.DO, LED186.DI
unnamed: LED186.DO, LED187.DI
unnamed: LED187.DO, LED188.DI
unnamed: LED188.DO, LED189.DI
unnamed: LED189.DO, LED190.DI
unnamed: LED190.DO, LED191.DI
unnamed: LED191.DO, LED192.DI
unnamed: LED192.DO, LED193.DI
unnamed: LED193.DO, LED194.DI
unnamed: LED194.DO, LED195.DI
unnamed: LED195.DO, LED196.DI
unnamed: LED196.DO, LED197.DI
unnamed: LED197.DO, LED198.DI
unnamed: LED198.DO, LED199.DI
unnamed: LED199.DO, LED200.DI
unnamed: LED200.DO, LED201.DI
unnamed: LED201.DO, LED202.DI
unnamed: LED202.DO, LED203.DI
unnamed: LED203.DO, LED204.DI
unnamed: LED204.DO, LED205.DI
unnamed: LED205.DO, LED206.DI
unnamed: LED206.DO, LED207.DI
unnamed: LED207.DO, LED208.DI
unnamed: LED208.DO, LED209.DI
unnamed: LED209.DO, LED210.DI
unnamed: LED210.DO, LED211.DI
unnamed: LED211.DO, LED212.DI
unnamed: LED212.DO, LED213.DI
unnamed: LED213.DO, LED214.DI
unnamed: LED214.DO, LED215.DI
unnamed: LED215.DO, LED216.DI

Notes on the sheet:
1.0
PI-LEDP20S-0010
Pi Plus sized LED-SHIM for Pi's 40-pin extension slot (c) Andriy Golovnya

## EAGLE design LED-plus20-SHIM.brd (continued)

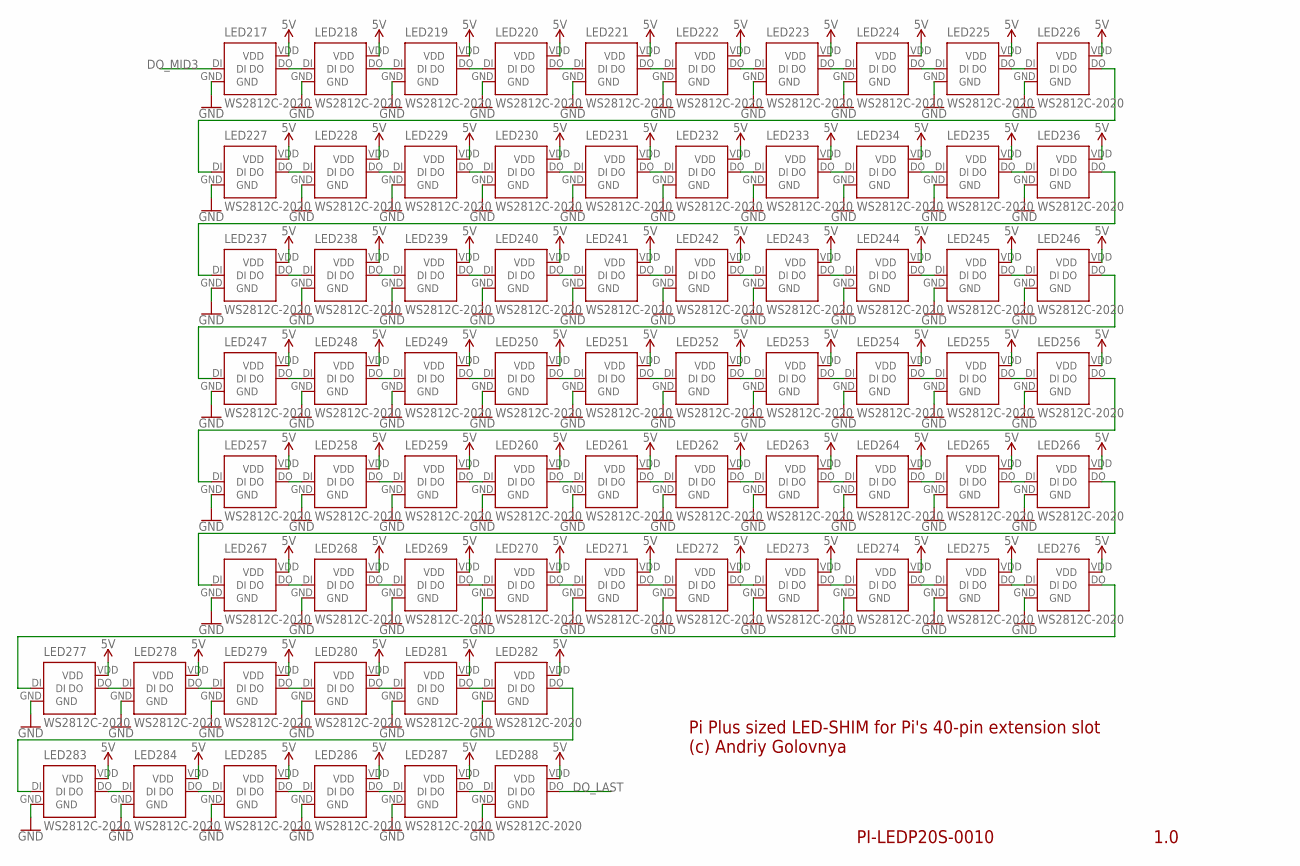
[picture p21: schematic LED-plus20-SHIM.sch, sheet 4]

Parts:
LED217, LED218, LED219, LED220, LED221, LED222, LED223, LED224, LED225, LED226, LED227, LED228, LED229, LED230, LED231, LED232, LED233, LED234, LED235, LED236, LED237, LED238, LED239, LED240, LED241, LED242, LED243, LED244, LED245, LED246, LED247, LED248, LED249, LED250, LED251, LED252, LED253, LED254, LED255, LED256, LED257, LED258, LED259, LED260, LED261, LED262, LED263, LED264, LED265, LED266, LED267, LED268, LED269, LED270, LED271, LED272, LED273, LED274, LED275, LED276, LED277, LED278, LED279, LED280, LED281, LED282, LED283, LED284, LED285, LED286, LED287, LED288: WS2812C-2020; WS2812X-2020

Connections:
5V: LED217.VDD, LED218.VDD, LED219.VDD, LED220.VDD, LED221.VDD, LED222.VDD, LED223.VDD, LED224.VDD, LED225.VDD, LED226.VDD, LED227.VDD, LED228.VDD, LED229.VDD, LED230.VDD, LED231.VDD, LED232.VDD, LED233.VDD, LED234.VDD, LED235.VDD, LED236.VDD, LED237.VDD, LED238.VDD, LED239.VDD, LED240.VDD, LED241.VDD, LED242.VDD, LED243.VDD, LED244.VDD, LED245.VDD, LED246.VDD, LED247.VDD, LED248.VDD, LED249.VDD, LED250.VDD, LED251.VDD, LED252.VDD, LED253.VDD, LED254.VDD, LED255.VDD, LED256.VDD, LED257.VDD, LED258.VDD, LED259.VDD, LED260.VDD, LED261.VDD, LED262.VDD, LED263.VDD, LED264.VDD, LED265.VDD, LED266.VDD, LED267.VDD, LED268.VDD, LED269.VDD, LED270.VDD, LED271.VDD, LED272.VDD, LED273.VDD, LED274.VDD, LED275.VDD, LED276.VDD, LED277.VDD, LED278.VDD, LED279.VDD, LED280.VDD, LED281.VDD, LED282.VDD, LED283.VDD, LED284.VDD, LED285.VDD, LED286.VDD, LED287.VDD, LED288.VDD; also elsewhere on the board
DO_LAST: LED288.DO; also elsewhere on the board
DO_MID3: LED217.DI; also elsewhere on the board
GND: LED217.GND, LED218.GND, LED219.GND, LED220.GND, LED221.GND, LED222.GND, LED223.GND, LED224.GND, LED225.GND, LED226.GND, LED227.GND, LED228.GND, LED229.GND, LED230.GND, LED231.GND, LED232.GND, LED233.GND, LED234.GND, LED235.GND, LED236.GND, LED237.GND, LED238.GND, LED239.GND, LED240.GND, LED241.GND, LED242.GND, LED243.GND, LED244.GND, LED245.GND, LED246.GND, LED247.GND, LED248.GND, LED249.GND, LED250.GND, LED251.GND, LED252.GND, LED253.GND, LED254.GND, LED255.GND, LED256.GND, LED257.GND, LED258.GND, LED259.GND, LED260.GND, LED261.GND, LED262.GND, LED263.GND, LED264.GND, LED265.GND, LED266.GND, LED267.GND, LED268.GND, LED269.GND, LED270.GND, LED271.GND, LED272.GND, LED273.GND, LED274.GND, LED275.GND, LED276.GND, LED277.GND, LED278.GND, LED279.GND, LED280.GND, LED281.GND, LED282.GND, LED283.GND, LED284.GND, LED285.GND, LED286.GND, LED287.GND, LED288.GND; also elsewhere on the board
unnamed: LED217.DO, LED218.DI
unnamed: LED218.DO, LED219.DI
unnamed: LED219.DO, LED220.DI
unnamed: LED220.DO, LED221.DI
unnamed: LED221.DO, LED222.DI
unnamed: LED222.DO, LED223.DI
unnamed: LED223.DO, LED224.DI
unnamed: LED224.DO, LED225.DI
unnamed: LED225.DO, LED226.DI
unnamed: LED226.DO, LED227.DI
unnamed: LED227.DO, LED228.DI
unnamed: LED228.DO, LED229.DI
unnamed: LED229.DO, LED230.DI
unnamed: LED230.DO, LED231.DI
unnamed: LED231.DO, LED232.DI
unnamed: LED232.DO, LED233.DI
unnamed: LED233.DO, LED234.DI
unnamed: LED234.DO, LED235.DI
unnamed: LED235.DO, LED236.DI
unnamed: LED236.DO, LED237.DI
unnamed: LED237.DO, LED238.DI
unnamed: LED238.DO, LED239.DI
unnamed: LED239.DO, LED240.DI
unnamed: LED240.DO, LED241.DI
unnamed: LED241.DO, LED242.DI
unnamed: LED242.DO, LED243.DI
unnamed: LED243.DO, LED244.DI
unnamed: LED244.DO, LED245.DI
unnamed: LED245.DO, LED246.DI
unnamed: LED246.DO, LED247.DI
unnamed: LED247.DO, LED248.DI
unnamed: LED248.DO, LED249.DI
unnamed: LED249.DO, LED250.DI
unnamed: LED250.DO, LED251.DI
unnamed: LED251.DO, LED252.DI
unnamed: LED252.DO, LED253.DI
unnamed: LED253.DO, LED254.DI
unnamed: LED254.DO, LED255.DI
unnamed: LED255.DO, LED256.DI
unnamed: LED256.DO, LED257.DI
unnamed: LED257.DO, LED258.DI
unnamed: LED258.DO, LED259.DI
unnamed: LED259.DO, LED260.DI
unnamed: LED260.DO, LED261.DI
unnamed: LED261.DO, LED262.DI
unnamed: LED262.DO, LED263.DI
unnamed: LED263.DO, LED264.DI
unnamed: LED264.DO, LED265.DI
unnamed: LED265.DO, LED266.DI
unnamed: LED266.DO, LED267.DI
unnamed: LED267.DO, LED268.DI
unnamed: LED268.DO, LED269.DI
unnamed: LED269.DO, LED270.DI
unnamed: LED270.DO, LED271.DI
unnamed: LED271.DO, LED272.DI
unnamed: LED272.DO, LED273.DI
unnamed: LED273.DO, LED274.DI
unnamed: LED274.DO, LED275.DI
unnamed: LED275.DO, LED276.DI
unnamed: LED276.DO, LED277.DI
unnamed: LED277.DO, LED278.DI
unnamed: LED278.DO, LED279.DI
unnamed: LED279.DO, LED280.DI
unnamed: LED280.DO, LED281.DI
unnamed: LED281.DO, LED282.DI
unnamed: LED282.DO, LED283.DI
unnamed: LED283.DO, LED284.DI
unnamed: LED284.DO, LED285.DI
unnamed: LED285.DO, LED286.DI
unnamed: LED286.DO, LED287.DI
unnamed: LED287.DO, LED288.DI

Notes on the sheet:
1.0
PI-LEDP20S-0010
Pi Plus sized LED-SHIM for Pi's 40-pin extension slot (c) Andriy Golovnya

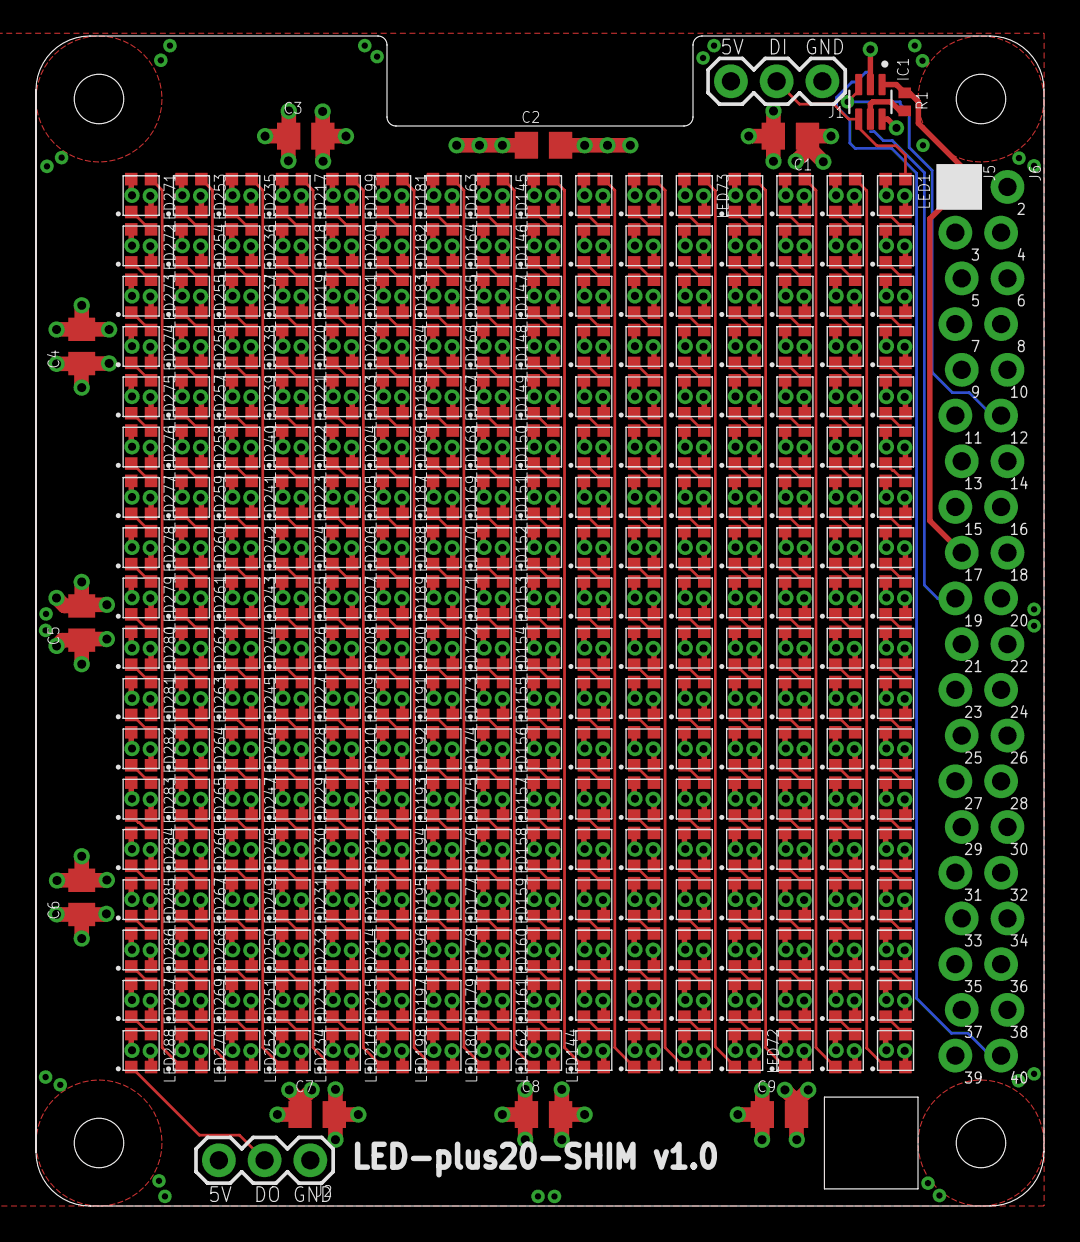
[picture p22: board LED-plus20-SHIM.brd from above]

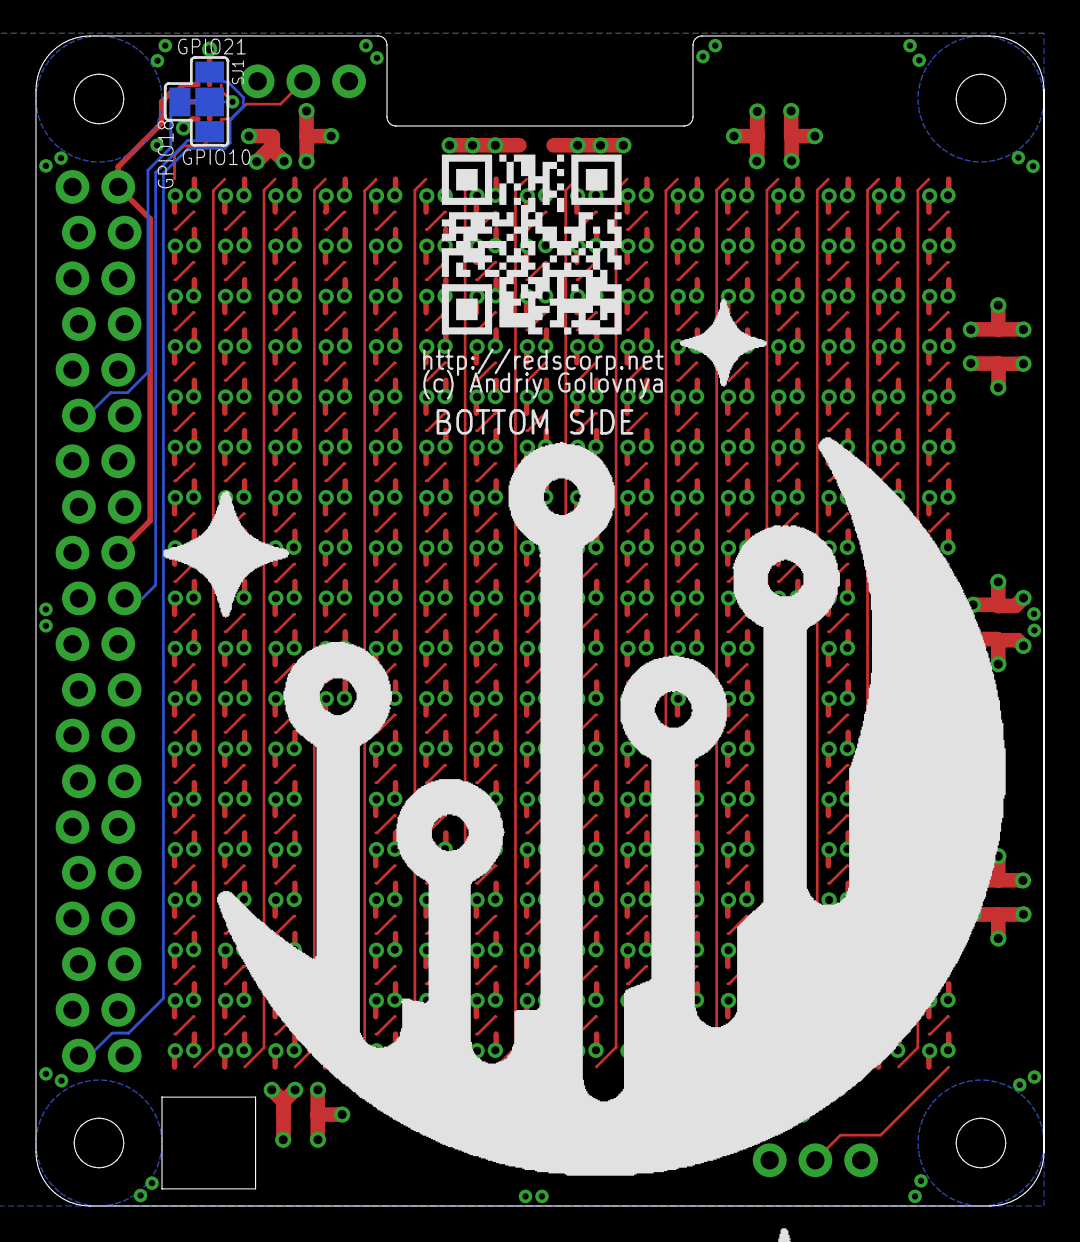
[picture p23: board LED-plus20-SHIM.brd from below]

Board: 4 copper layers, 56.0 x 65.0 mm, 306 parts (3 on the bottom side), 297 nets.

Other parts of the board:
LOGO3: RSNURL_QR_10MM

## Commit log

2021-05-10 Added initial LED-zero-SHIM board design.
    [LED-zero-SHIM.brd, LED-zero-SHIM.sch]
2021-05-11 added buffer and caps
    [LED-zero-SHIM.brd, LED-zero-SHIM.sch]
2021-05-11 Added solder joint for DATA input configuration
    [LED-zero-SHIM.brd, LED-zero-SHIM.sch]
2021-05-12 Use C veriant of LED insted of B.
    [LED-zero-SHIM.brd, LED-zero-SHIM.sch]
2021-05-12 Added some traces.
    [LED-zero-SHIM.brd, LED-zero-SHIM.sch]
2021-05-13 Made the board 4-layer and routed it completely.
    [LED-zero-SHIM.brd, LED-zero-SHIM.sch]
2021-05-13 Generated PDF schematics.
2021-05-13 Generated CAM, BoM, PnP files.
    [LED-zero-SHIM_2021-05-13-BoM.xlsx, LED-zero-SHIM_2021-05-13-PnP.xlsx]
2021-05-13 Moved few traces around for better power delivery. Generated new CAM files.
    [LED-zero-SHIM.brd]
2021-05-13 changed R1 rotation
    [LED-zero-SHIM_2021-05-13-PnP.xlsx]
2021-05-13 Added LED-mini-SHIM board.
    [LED-mini-SHIM.brd, LED-mini-SHIM.sch]
2021-05-15 Fixed parts orientation in PnP file.
    [LED-mini-SHIM_2021-05-13-PnP.xlsx]
2021-05-15 Added panelized version of LED-mini-SHIM board. Generated CAM, BoM and PnP files.
    [LED-mini-SHIM-x2.brd, LED-mini-SHIM-x2_2021-05-13-BoM.xlsx, LED-mini-SHIM-x2_2021-05-13-PnP.xlsx]
2021-05-16 Removed holes. Generated new CAM files.
    [LED-mini-SHIM-x2.brd]
2021-05-21 Moved some traces and vias around
    [LED-zero-SHIM.brd]
2021-06-07 Fixed some traces on zero SHIM. Generated PNG preview. Generated CAM files.
    [LED-zero-SHIM.brd]
2021-06-07 Added base of plus board.
    [LED-plus-SHIM.brd, LED-plus-SHIM.sch]
2021-06-07 Fixed some texts
    [LED-plus-SHIM.brd, LED-plus-SHIM.sch]
2021-06-08 Finished tracing plus SHIM board.
    [LED-plus-SHIM.brd, LED-plus-SHIM.sch]
2021-06-09 Moved few traces around.
    [LED-plus-SHIM.brd]
2021-06-09 Generated PDF schematics
2021-06-10 Generated BoM file. Generated PnP file.
    [LED-plus-SHIM_2021-06-09-BoM.xlsx, LED-plus-SHIM_2021-06-09-PnP.xlsx]
2021-06-11 Added few vias
    [LED-plus-SHIM.brd]
2021-06-29 Renamed files
    [LED-mini20-SHIM-x2.brd, LED-mini20-SHIM-x2_2021-05-13-BoM.xlsx, LED-mini20-SHIM-x2_2021-05-13-PnP.xlsx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]
2021-06-29 Updated texts. Generated CAM files. Generated PNG preview. Generated PDF schematics.
    [LED-mini20-SHIM-x2.brd, LED-mini20-SHIM.brd, LED-mini20-SHIM.sch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]
2021-06-29 Added mini35 board.
    [LED-mini35-SHIM.brd, LED-mini35-SHIM.sch]
2021-06-29 Generated CAM files. Generated PNG preview. Generated PDF schematics.
2021-06-30 Cleaned mounting hole screwing area of copper. Generated CAM files.
    [LED-plus20-SHIM.brd, LED-zero20-SHIM.brd]
2021-07-27 Added one more 35mm LED to the mini-board. Generated CAM files. Generated PDF schematics. Generated PNG preview.
    [LED-mini35-SHIM.brd, LED-mini35-SHIM.sch]
2021-07-29 Make round cutouts in screwing area. Generated CAM files. Generated PNG previews.
    [LED-plus20-SHIM.brd, LED-zero20-SHIM.brd]
2021-09-03 Generated BoM and PnP files.
    [LED-mini35-SHIM_2021-07-27-BoM.xlsx, LED-mini35-SHIM_2021-07-27-PnP.xlsx]
2021-09-03 Fixed VIA. Generated CAM files. Generated PNG preview. Renamed BoM and PnP files.
    [LED-mini35-SHIM.brd, LED-mini35-SHIM_2021-09-03-BoM.xlsx, LED-mini35-SHIM_2021-09-03-PnP.xlsx]
2021-09-03 Added x2 version of mini35 board. Generated CAM files.
    [LED-mini35-SHIM-x2.brd]
2021-09-04 Added 35mm LDE zero board. Generated CAM files. Generated PNG preview. Generated PDF schematics.
    [LED-zero35-SHIM.brd, LED-zero35-SHIM.sch]
2021-09-06 Base of 35mm size LED board.
    [LED-plus35-SHIM.brd, LED-plus35-SHIM.sch]
2021-09-07 Routed 35 plus board. Generated CAM files. Generated PNG preview. Generated PDF schematics.
    [LED-plus35-SHIM.brd]
2021-09-10 Fixed x2 mini35 BoM.
    [LED-mini35-SHIM_x2_2021-09-03-BoM.xlsx]
2021-09-10 Generated BoM and PnP files for plus35 board.
    [LED-plus35-SHIM_2021-09-07-BoM.xlsx, LED-plus35-SHIM_2021-09-07-PnP.xlsx]
2021-09-11 Fixed orientation of ws2812b-mini LEDs in PnP files. fixed naming of x2 BoM and PnP files.
    [LED-mini35-SHIM-x2_2021-09-03-BoM.xlsx, LED-mini35-SHIM-x2_2021-09-03-PnP.xlsx, LED-mini35-SHIM_x2_2021-09-03-PnP.xlsx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]
2021-09-24 Added cut corner to ws2812b-mini footprint. Generated CAM files. Generated PNG preview.
    [LED-mini35-SHIM-x2.brd, LED-mini35-SHIM.brd, LED-mini35-SHIM.sch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]

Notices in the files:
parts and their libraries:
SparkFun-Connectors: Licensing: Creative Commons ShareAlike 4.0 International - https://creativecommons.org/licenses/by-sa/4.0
